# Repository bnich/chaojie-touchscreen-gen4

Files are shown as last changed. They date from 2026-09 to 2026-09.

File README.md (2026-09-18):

# Chaojie Gen 4 5" touchscreen — handlebar mount and rear cowl

A parametric, 3D-printable handlebar mount for the **Chaojie `CJ-V5-04`** 5" touchscreen display —
the panel sold with FarDriver controllers by E-Conic, EMF and others. It ships with no bracket.

<p align="center">
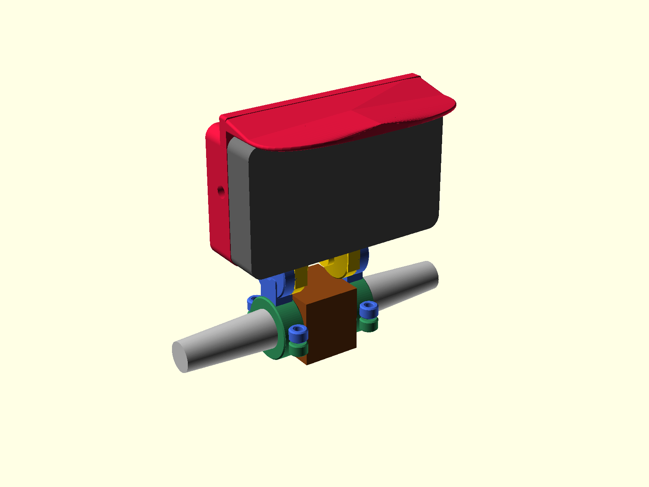
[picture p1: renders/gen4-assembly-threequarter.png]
Three-quarter render of the assembled mount: the display carried on a yoke with a toothed tilt joint at each side, two clamps on the handlebar either side of the centre bracket, and a red rear cowl with a curved sun visor projecting over the screen
  
</p>

A structural **yoke** bolts to the display's three M5 inserts and carries a 48-tooth face-spline tilt
joint at **each** side, on one shared axis parallel to the bar. Two **clamps** grip the handlebar on
**both** sides of the centre bracket. A **cowl** encloses the back of the display and carries a sun
visor over the glass.

| | |
|---|---|
| Printed parts | 4 distinct, **6 on the bike** (the clamp arm and cap print twice) |
| Tilt | 48 teeth, **7.5° per click**; tooth ring r = 12…20 mm, finest pitch 1.57 mm |
| Screen height above the bar | bottom edge **52 mm**, top edge **146 mm** |
| Grip on the bar | **~81 mm** total, split either side of the steering axis |
| Sun visor | **33 mm** past the glass; shades **27.7 %** of the screen at 45° off the screen normal |
| Material | ASA (PC or PETG-CF also suitable) |
| Filament | **262 cm³** for the six printed parts — about 320 g in ASA |

---

## Exploded view

<p align="center">
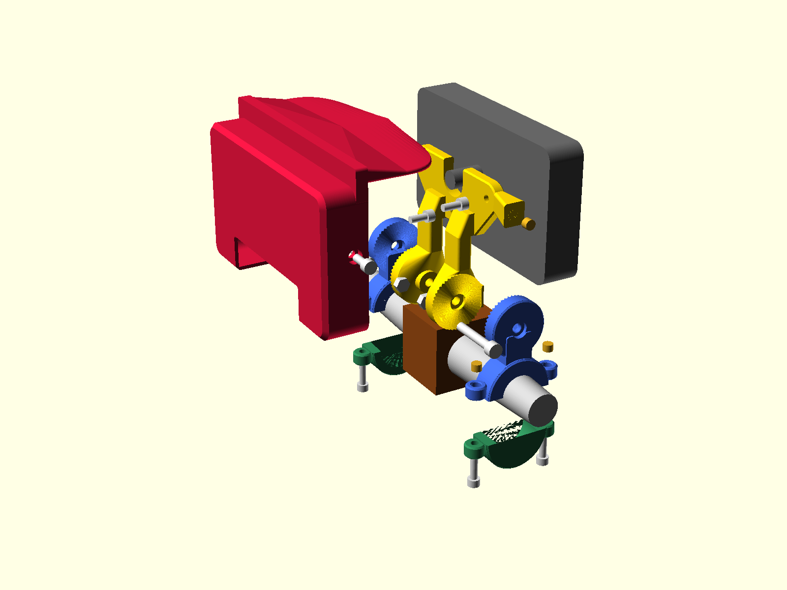
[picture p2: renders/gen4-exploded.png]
Exploded diagram: the red cowl with its two side screws, the gold yoke with three M5 bolts and two heat-set inserts, the grey display, and the two blue clamp arms with their green caps, clamp bolts, pivot bolts and nuts, on the silver handlebar either side of the brown centre bracket
  
</p>

| Colour | Item |
|---|---|
| Red | Cowl (printed) |
| Gold | Yoke (printed) |
| Blue | Clamp arm (printed, ×2) |
| Green | Clamp cap (printed, ×2) |
| Dark grey | Display — not printed |
| Silver / brown | Handlebar and its centre bracket — not printed |
| Brass | Heat-set inserts |

---

## Hardware

| Joint | Fastener | Count | Notes |
|---|---|---|---|
| Display → yoke | **M5 × 12** socket cap | 3 | ⚠️ **No washer, never longer.** The display's thread is 5 mm deep |
| Bar clamp, arm → cap | **M5 × 16** socket cap | 4 | Into inserts in the arm; heads counterbored into the cap's underside |
| Cowl → yoke | **M5 × 12** socket cap | 2 | Into inserts in the yoke's side ears; heads recess below the cowl's side face |
| Tilt pivot | **M6 × 35** + nyloc + plain washer | 2 | **One per side**, each through its own pivot only. 26.1 mm grip, 7.3 mm into the nut |
| Heat-set inserts | **M5, Ø7 × 5 long** | 6 | 4 across the two arms (2 per arm), 2 in the yoke; buy spares |
| Clamp bore liner | inner-tube rubber strip | 2 | Protects the bar and takes up ovality |

Medium-strength threadlocker on the three display bolts.

**Insert placement.** Two per clamp arm, pressed into the top face of each ear. Two in the yoke,
pressed into the outer face of each side ear. None in the cap, none in the cowl.

⛔ **No insert at the tilt pivot.** The M6 runs up the spline's own Ø12 central bore; an M6 insert is
Ø8 and would leave 2 mm of wall in the middle of the tooth ring. It is also the only joint here loaded
purely in tension, where a through-bolt and nut put the plastic in compression between two steel
faces. Use the through-bolt.

### Bolt lengths are derived

Each length is computed from the stack it crosses and asserted in the model. Change a part thickness
and the render stops and names the size it now needs.

```
pivot_grip = leg_w/2 + yoke_tip_h + spline_seat + arm_tip_h − pivot_head_sink
           = 9 + 6 + 7.6 + 6 − 2.5  =  26.1 mm   →  M6 × 35 with a 1.6 mm washer
```

---

## Does this fit my display?

It fits the **`CJ-V5-04`** — the 5", 800 × 480, DC 12–96 V panel with a `DJ7091A-2.8-11` 9-pin main
lead and a cable bundle emerging from the middle of its back.

It does **not** fit the 3" `CJ-V3-01` or the Gen 3 touchscreen — different housings, different hole
patterns.

<p align="center">
  Dimensioned rear-face drawing of the Chaojie CJ-V5-04: three M5 mounting holes at (39.50, 40.9), (120.50, 40.9) and (80.00, 63.28), the diameter 21.7 cable-boot collar at the centre, and the flat bearing band between Y 23.0 and Y 71.6
</p>

Three M5 holes, 81.0 mm apart, with a third 22.39 mm below the centre of that pair. Full dimensions
in [docs/display-geometry.md](docs/display-geometry.md).

---

## Fitting it to your bar

The clamp bore is a **cone**, not a cylinder, because the REVV1 FS bar tapers 1:10 through the clamp
zone. Measure the diameter at three points along the run — a single reading cannot tell a tapered bar
from a parallel one.

```openscad
bar_d0    = 32.0;   // Ø where the clamp's inboard face sits
bar_taper = 0.1;    // Ø lost per mm outward; 0 for a parallel bar
bar_run   = 20;     // usable straight length before the bar curves
arm_len   = 45;     // pivot above the bar centreline
```

Everything else is derived. See [docs/bike-fitment.md](docs/bike-fitment.md).

---

## Printing

ASA, 0.2 mm layers (0.16 mm for the cowl), 4 walls minimum, 40–50 % infill on the yoke and arms. The
cowl is designed around a 2.4 mm wall — six perimeters at 0.4 mm.

**Print order:** `insert_coupon` → `gauge` → `brow_test` → `yoke` → `arm` + `cap` (×2 each) → `cowl`.

Per-part orientation, measured overhang figures and settings: [docs/printing.md](docs/printing.md).

<p align="center">
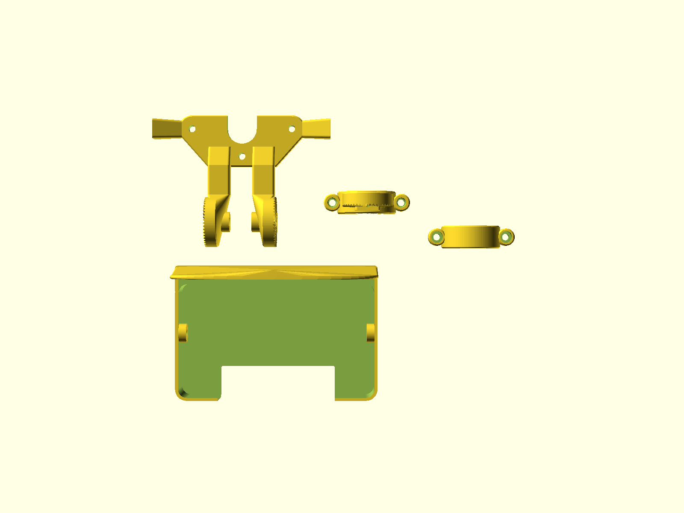
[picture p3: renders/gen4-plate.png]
The four printable parts -- yoke, arm, cap and cowl -- laid flat on one print plate in their print orientation
  
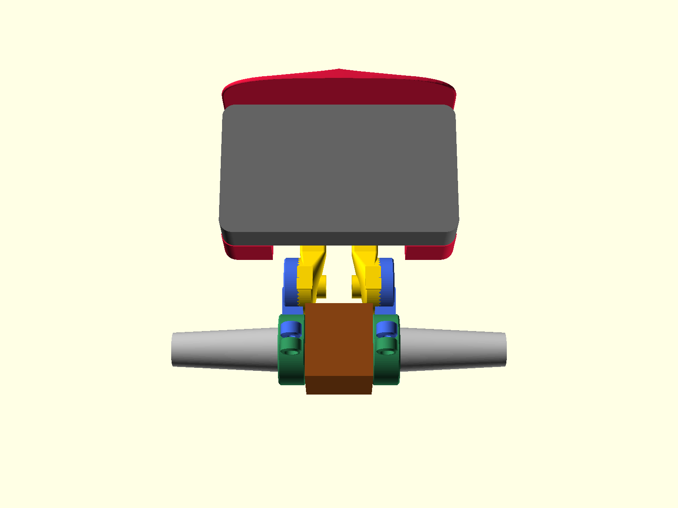
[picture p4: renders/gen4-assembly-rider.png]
The assembly seen from the saddle: the screen fills the frame with the sun visor across the top and both clamps visible flanking the centre bracket
  
</p>

---

## Assembly

1. Press the six heat-set inserts — two in each clamp arm, two in the yoke.
2. Bolt the yoke to the display — three M5 × 12, run down by hand first, then threadlocker.
3. Fit a clamp to each side of the centre bracket, butting its faces.
4. Mesh each spline at the angle you want and run the M6 through with its washer and nyloc.
5. Hook the cowl's top lip over the display's top edge, rotate it down, and drive one M5 × 12 into
   each side.

Full sequence, tilt adjustment and the 5 mm-thread warning: [docs/assembly.md](docs/assembly.md).

---

## Documentation

| | |
|---|---|
| **[docs/display-geometry.md](docs/display-geometry.md)** | Every measurement of the display's back, and the three things that catch people out |
| **[docs/design-notes.md](docs/design-notes.md)** | The design constraints and what each one protects |
| **[docs/bike-fitment.md](docs/bike-fitment.md)** | What the clamp needs from your handlebar, and how to adapt it to a different bar |
| **[docs/spline-verification.md](docs/spline-verification.md)** | How the tilt joint's teeth were proven to mesh, and why the obvious checks give wrong answers |
| **[docs/printing.md](docs/printing.md)** | Material, per-part orientation, measured overhang, settings, print order |
| **[docs/assembly.md](docs/assembly.md)** | Hardware, order of assembly, setting the tilt |

## Layout

```
src/      gen4-display-mount.scad   — the whole model; every part, one file
stl/      pre-built exports
renders/  drawings and preview images
docs/     the six documents above
tools/    build.sh          export every part and run every gate
          render-gen4.sh    every STL and every PNG
          check_stl.py      bounding box
          check_fit.py      clearance, on a second boolean engine
          check_throat.py   smallest load-bearing section, angle-swept
          check_fixing.py   does a screw cross one part and land in the other
          check_shade.py    what the sun visor actually shades
          check_necks.py    erode the part and see what falls off
          check_print.py    does any layer start in mid-air?
```

## Building from source

Needs [OpenSCAD](https://openscad.org/) (2021.01) and Python 3 with
`trimesh manifold3d numpy scipy networkx rtree`.

```bash
./tools/build.sh          # export every part, run every gate
./tools/render-gen4.sh    # the above, plus every PNG
openscad -o out.stl -D 'part="yoke"' src/gen4-display-mount.scad
```

Part names: `gauge`, `insert_coupon`, `spline_test`, `pivot_puck_test`, `yoke_leg_test`,
`yoke_plate_test`, `yoke`, `arm`, `cap`, `cowl`, `brow_test`, `plate`, `assembly`, `exploded`. An
unrecognised name fails loudly.

The build is gated on mesh integrity, fill against hand-computed expectations, minimum load-bearing
section over swept cutting planes, clearance between every part pair on a second boolean engine, that
the tilt joint pitches rather than rolls, that each screw crosses one part and lands in material in
the next, and what the sun visor measurably shades. Each gate has been run against geometry known to
be broken and confirmed to fail on it.

---

## Three things guarded by assertions

1. **The cable-boot slot opens upward.** A downward slot cuts off the lone M5.
2. **The pivot sits below the housing.** Anywhere higher and the toothed face covers that bolt's head.
3. **Bolt length minus part thickness lands in 3–4 mm.** The display's thread is 5 mm deep.

---

## Contributing

Issues and pull requests welcome — especially measurements from other units and photos of it fitted.
See [CONTRIBUTING.md](CONTRIBUTING.md).

## Licence

[CC BY-SA 4.0](LICENSE). Print it, modify it, sell prints of it — credit the source and share your
changes under the same terms.

The Chaojie factory manual is **not** redistributed here; it is Chaojie's document. The measurements
derived from it are facts and are published freely.

## Disclaimer

This mounts an electronic display to a moving vehicle. Nothing here has been tested to any standard.
**Proof-load it before you trust it, and re-check every fastener after the first ride.** You are
responsible for what you bolt to your own bike.

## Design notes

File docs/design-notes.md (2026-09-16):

# Design constraints

Read this before changing the model. Several things that look like arbitrary choices are forced by
the display, and "simplifying" them produces a part that renders fine and fails on the bike.

The model encodes each of these as an `assert()`, so if you change a parameter and break one, the
render stops and tells you which constraint you violated. **If an assertion fires, the number you
changed was wrong — not the assertion.**

---

## Two clamps, not one (2026-09-15)

The original design hung the whole display off **one** narrow yoke arm, necking down through the
cowl's opening to a **single** spline disc and **one** clamp on one side of the centre bracket — a
cantilever on a thin section, on a vehicle with no drivetrain damping. The owner rejected it:

> "That is a bad design. We should be attaching on both sides of the handlebars. There is a tiny
> sliver of plastic supporting the entire display."

Correct call — a two-sided mount was considered and discussed at design time, and it was wrongly
argued against then. Its advantages are exactly what a one-sided cantilever gives up:

- **Grip spread across ~81 mm** (an 18 mm clamp on each side of the 45 mm bracket) instead of 18 mm on
  one side of it.
- **The display centres itself.** With a spline on each side, mirror images of each other, there is no
  crank left to get wrong or drift out of sync with the bracket width — `pivot_x_r` (and its mirror
  `pivot_x_l`) is *derived* from the bracket's own measured 45 mm, not chosen and then checked against
  it after the fact.
- **A proper axle, not one disc taking the whole moment.** The tilt hinge is now a spline at *each* end
  of one shared axis, coaxial, each mating its own clamp — closer to a bicycle hub's two bearings than
  to a single boss cantilevered off a plate.
- **The load is shared and mostly in shear**, not a bending moment concentrated on one thin arm.

### One clamp part, mirrored, not two

`arm()`/`cap()` are unchanged in kind — still a two-piece bar clamp with a tapered bore and a male
spline — but there is now no `arm_crank`: each clamp roots its own spline at its own bare Y-midpoint
(`clamp_x0 + clamp_w/2`, no offset), and *the same printed part* is used on both sides. This works
because the clamp's own solid — round tube, symmetric ear bosses, a centred rib — is already
left-right symmetric about its own local X=0, and the male spline's tooth pattern (phase 0, an
arithmetic sequence of angles symmetric under negation) reproduces itself exactly under a mirror about
any plane containing its own axis. `clamp_seat(side)` (the renamed, generalised `arm_seat()`) seats the
right clamp with the same translate/rotate this file has always used, and seats the left one as
`mirror([1,0,0])` of that exact result — not a second, independently-solved rotation. The one subtlety
worth recording: mirroring about the plane **perpendicular to** the shared hinge axis (X=0, and the
hinge runs along X) **commutes** with the pitch rotation `theta`, because a reflection whose own axis
*is* the rotation axis negates both the axis and the angle, and the two negations cancel — so both
clamps use the *same* `theta`, not opposite-signed ones. Confirmed against the actual exported geometry
by the same pitch-acceptance test described below, not trusted on the algebra alone.

⚠️ **Left side of the bar is unmeasured.** Only the right side was put under calipers
(`docs/bike-fitment.md`). `bar_d0`/`bar_taper`/`bar_run` are **temporarily assumed** to mirror on the
left — flagged at their own definition in `src/gen4-display-mount.scad`. If the left side turns out to
differ, the two clamps stop being one shared part.

### Minimum cross-section in the load path

⭐ **Corrected 2026-09-15, after a real defect.** This table used to claim no station on the path was a
thin cantilevered sliver, including a rising-rib figure (`arm_w × ~8mm = 160mm²`) that was never
actually measured — a hand guess from the two end profiles, not a scan of the part in between. The
owner found the truth by eye: *"Ensure that there is enough material holding the clamp to the
handlebars to the toothed piece. It looks very thin."* They were right. A station-by-station section
scan (`tools/build.sh`, added the same day — intersect the part with a 1mm slab at each station,
volume ÷ thickness) confirmed it: the clamp's own rising rib had a "vertical riser" stage built from
two `taper_wp()` waypoints at the *same* Y, which cannot gain any real Y-thickness — a `hull()` between
two same-Y markers stays confined to that marker's own 0.2mm thickness for its entire run (the
mechanism, not just the number: `src/gen4-display-mount.scad`'s own block comment above `arm()`'s Stage
1). Measured minimum: **4 mm²** — a 20mm-wide, 0.2mm-thick knife edge — not the claimed 160. Every
other check stayed green throughout: watertight, 0 boundary, 0 non-manifold, 1 component, a plausible
total volume, clearance clean, a normal-looking render. None of them measure a cross-section; volume
catches a hollow part, nothing was watching minimum section. Fixed by widening that riser to a real
Y-span (`clamp_riser_y0`..`clamp_riser_y1`, 14mm, inboard of the clamp tube's own edges) instead of a
single Y. `tools/build.sh` now scans every station along both this path and the yoke leg's own, and
fails the build if either drops below a floor — the permanent check the project didn't have before.

### ⚠️ A section scan is only as honest as the plane it cuts on

The scan above cuts perpendicular to one axis. On the yoke, that axis was the one direction the weak
spot looked strong in, and the scan passed a leg that was hanging off the bearing plate by almost
nothing. Owner, looking at the side view: *"there is only a thin bit of plastic connecting where the
back of the part mounts to the display to the rest of the yoke, this should be thicker."* Right again,
and again after a check had passed it.

The cause is a genuine constraint collision. Material at low Z has to stay inside the display's flat
band (outside it the rear shell chamfers away), which confines the leg's climb from the plate to the
riser — **13 mm of Z across 2.32 mm of Y**, a slope of 5.6:1. That is not a taper, it is a shear web
18 mm wide and about 2 mm thick. Cut across Y it measures 194.6 mm²; cut at 72–78°, the way the load
actually peels the leg off the plate, it measures **36.4 mm²**.

**The fix is a gusset**, not a wider Stage A — the 2.32 mm is forced and that constraint is real.
Instead the load now also runs through the one place with no clearance constraint at all: directly
above the bearing plate. A wedge buried `yoke_gusset_bite` (3 mm) into the plate's top face runs north
to just clear of the boot's relief pocket and ramps up to meet the riser. The plate is solid 18-of-18
mm under the leg's whole X band there (measured on `yoke-plate-test.stl`, not assumed), so the
gusset's underside is fully carried: **no overhang, no support, and the yoke's down-facing area is
unchanged at 2644 mm²**. Throat **36.4 → 182.2 mm², a 5× improvement**, for 4.3 cm³ of extra plastic.

`tools/check_throat.py` is the permanent check. It does not pick a plane: it sweeps the cutting angle
and reports the smallest section that *verifiably separates* the load's origin from its destination —
cut the solid, and the piece holding the destination must not hold the origin. Without that
separation test the search just finds the part's own edges, where a plane clips a corner and the area
tends to zero. It gates the yoke at 150 mm² and the arm at 200 mm², and it was proven to fire against
the pre-gusset geometry (36.7 mm², 113 mm² under the floor).

Walking the path today — every figure measured, none estimated from end profiles:

| Station | Cross-section (measured) |
|---|---|
| Bearing plate (bolted to the display) | `yoke_t` (8 mm) full-thickness slab, widened at its base to root both legs |
| **Plate → pivot, worst plane at any angle** | **182.2 mm²** per leg (was 36.4 mm² before the gusset) |
| Each leg's own run, cut across Y | ~194 mm² per leg |
| The spline (each pivot) | Ø40 Hirth coupling, all 48 teeth engaging at once across a ~1144 mm² annulus — a distributed contact, not a point |
| Each clamp's own rising rib | **284 mm² minimum** (widened 2026-09-15 from a 4 mm² knife edge — see above) |
| Clamp → male spline, worst plane at any angle | **236.9 mm²** — measured the same swept way, so the arm is known clear of this failure mode rather than assumed clear |
| Each clamp body | Ø48 tube over a ≥Ø28 bore — a ring, not a sliver |

**The minimum on the whole path is now the leg's own run, ~182–194 mm² per leg, and there are two of
them in parallel.** That is the right place for the limit to sit: it is uniform section, not a
junction. It is set by `leg_w` = 18 mm, reduced from the old single arm's 26 mm as a deliberate trade
for clearance from the lone M5's socket sweep (the legs are no longer centred under it — see
`pivot_x_r`'s own assertion in the model), not as a structural economy. There is headroom to widen it
again if a print or a ride ever calls for it.

---

## The two forced constraints

### 1. The boot slot opens upward

Covered in [display-geometry.md §4.3](display-geometry.md). Short version: the loom exits the middle
of the back, its connectors are too big to thread through any closed hole, and a downward slot would
cut off the lone M5. Up the centreline is the only direction that works.

This is why the bearing plate is a wide, gusseted shape — three bolt pads plus two more hull anchors
(one per leg root, ⭐ 2026-09-15) — rather than a plain rectangle: every anchor has to stay clipped to
the flat band and clear of the boot's own upward slot.

### 2. The pivot sits well below the housing — DM-6, re-derived for a bar-parallel axis

**The tilt joint's axis has to be parallel to the handlebar**, not the display's own normal. A hinge
that swings the display's pitch (up/down, the whole point of a tilt mount) needs its axis running
across the bike, the same line the bar lies on — turning about the display's own normal instead just
rolls the screen in its own plane, which is a defect this design carried and fixed once (2026-09-14),
documented here so the reasoning survives, not the mistake.

That axis choice changes what "the pivot sits below the housing" has to defend against. With the axis
along the bar (model X), the toothed face's own reach along its axis is only a few millimetres — it
sits deep inside the display's own width, with no sideways offset to hide behind the way a normal-axis
boss could hide behind standoff depth. Clearance for both the display and the lone M5 has to come from
where the disc sits in the OTHER two axes (Y and Z), not from how far it stands off in Z.

**The display.** The disc is a Ø40 circle in the Y-Z plane. Placed entirely below the display's own
bottom edge in Y (rather than split across a Y/Z diagonal — simpler to build and reason about, and it
costs nothing since there is open air below the display anyway), it needs no Z clearance to avoid the
housing at all: its bottom edge is at model Y −70, 23 mm below the display's own bottom edge, so even
at the disc's nearest point (Y −50) there is a full 3 mm of air past the housing.

**The lone M5.** Automatically satisfied by the same margin — the bolt sits at model Y −16.3, deep
inside the display's own footprint, far closer to the display than to a pivot 70 mm below it. The
connecting arm's own root/riser staging (unchanged by this rework) still keeps material flush at the
bearing-plate thickness until it is past the bolt's own Y, exactly as before, so nothing between the
plate and the disc can shadow the bolt either.

**The cost, twice over.** The display's centre of mass now sits **70 mm** above the pivot (was 53 mm)
— on a ~0.4 kg display, ~0.34 N·m static, still comfortably inside what this spline is sized for. And
because both clearances (display, and the clamp-vs-spline check in `docs/bike-fitment.md`) now stack
on the SAME axis instead of two independent ones, the display sits **52 mm** above the bar's top
surface at the reference (theta=0) pose instead of the originally-chosen 35 mm — see
`docs/bike-fitment.md` for the full number and why a more compact, diagonal-clearance placement was
not pursued.

---

## Why a toothed face spline, not friction

A friction pivot — a bolt clamping two smooth faces — is the obvious cheap answer and it is the wrong
one here. Plastic-on-plastic under vibration relaxes; on a hub-motor vehicle with no drivetrain
damping it will need re-nipping, and eventually the faces polish and it stops holding at all. A
screen that droops at 40 mph is a permanent small annoyance.

A face spline carries the moment on **teeth** instead of friction, so an angle set today is still set
in a year. You trade infinite adjustment for 7.5° steps.

**Why a printed spline is trustworthy:** a face spline engages *every tooth at once*. With 48 teeth
the per-tooth load is tiny, so FDM's weakness across layer lines stops governing — which is what lets
the yoke print flat on its bearing face, the orientation its plate and bolt pads want anyway.

The model carries a **`teeth = false`** switch. Once you have settled on an angle from riding, the
same file prints the joint solid, with nothing left to loosen.

---

## Why two parts instead of one

The back of this display faces forward on a moped — it is a surface people see, not a bracket hidden
behind a screen. So there is a cosmetic cowl over the structural yoke.

Splitting them lets each be optimised separately:

- the **yoke** is oriented and ribbed for strength, and printed bearing-face-down;
- the **cowl** is thin-walled and printed **face-down on a textured sheet**, so the surface people see
  is one uniform moulded-looking texture instead of stacked layer lines.

It also means the cowl comes off for service **without ever disturbing those 5 mm threads**, which is
the fastener you least want to cycle.

---

## The sun visor

The cowl carries a visor over the glass. It is not decoration. Chaojie does not publish this panel's
brightness, and it is a 5" glossy screen on an open vehicle — daylight readability is its real
weakness. The visor costs nothing to print as part of a cowl you are making anyway, and it keeps rain
and low winter sun off the glass too.

### What it measures

`tools/check_shade.py` fires rays at the glass from a given sun angle and reports what fraction of
the screen the cowl actually blocks. The angle is measured **from the screen's own normal**, not from
the horizon — so "45°" means the sun is 45° off the direction the screen is pointing, whatever the
tilt joint is set to. That is the quantity that decides shading; world elevation is not.

| Sun, off the screen normal | Screen shaded | Shadow reaches, from the top edge |
|---|---|---|
| 45° | **27.7 %** | 28.2 mm |
| 60° | 49.3 % | 49.3 mm |
| 75° | 94.0 % | 94.0 mm |

Projection past the glass is **33 mm**. `tools/build.sh` holds a 20 % floor at 45°.

### ⚠️ Width is the lever, not projection

The obvious way to shade more is a longer nose. It does almost nothing here, and this was measured
rather than argued. On the earlier straight-taper visor, stretching projection from 33 mm to 45 mm
moved 45° shade 14.8 % → 17.2 %, and 60 mm reached only 20.4 % — while the shadow's depth down the
screen did not move at all, staying at 14.1 mm in every case. A row of screen is shaded only where
the visor is actually *over* it, so a visor that has tapered to a 2 mm spike by mid-projection leaves
the screen's outer columns in full sun however far that spike reaches.

So the plan curve is a **superellipse** (`brow_plan_n = 3`): full width at the glass plane, holding
most of it for most of the run, then turning back to a blunt rounded nose over the last few
millimetres. Same projection, same rounded silhouette, 27.7 % instead of 14.8 %. Raising the exponent
squares the curve off — more shade, blockier nose; lowering it toward 2 gives a sleek ellipse and
less shade. Move it and re-run the shade test.

### ⚠️ The bearing plate is a truss — its reach depends on Y

The plate is not a rectangle. Its outer edge runs diagonally from the bolt-hole wings down toward the
legs, so how far out in X it reaches depends strongly on where in Y you look:

| Y | plate reaches |
|---|---|
| +6 | **x = 51.5** (widest) |
| −4 | x = 46.0 |
| −12 | x = 39.0 |
| −24 | x = 28.2 |

Anything rooted into the plate has to be placed against that, not against its bounding box. The cowl's
side ears were first placed at y = −4 starting at x = 51 — five millimetres outboard of the plate
altogether, meeting it at a corner, sharing **2.3 mm³** of volume with it out of 6670. They are now at
**y = +6**, the widest line, rooted at x = 40 where the plate is solid from y = −10 to +16.

⛔ **A section scan cannot catch that class of defect at any angle**, including the hemisphere sweep
in `tools/check_throat.py`, which reported 112 mm² on the broken ear. The plane that comes closest to
separating an ear also slices a large area of plate carrying none of the ear's load. To ask whether a
feature is *attached*, measure the **shared volume** of the two solids — `tools/build.sh`'s cowl-ear
bond gate — not a cross-section.

### The underside is flat on purpose

Every station's profile sits on one shared plane, `brow_y0` (3 mm above the display's top edge).
Drooping the nose would shade more, and it is tempting — but the visor extends *toward the rider*,
and anything that shades the sun at a given angle also blocks the rider's eye at that angle. A drooped
nose eats the top of the screen from an upright riding position. Shade above ~45° is what the tilt
joint is for: point the screen at your eyes and the sun goes off-normal without the visor moving.

⬜ **Not bench-verified.** Print `brow_test` and hold it against the screen on the bike, seated
normally, before committing the cowl. The numbers above are ray-cast measurements of the model, not
of a printed part in sunlight.

---

## Making it look like a product rather than a print

Applied without exception:

| | |
|---|---|
| **R3 / R2 / R1** | **No edge is left sharp.** R3 on the cowl's outer perimeter, R2 on every other visible edge, R1 internal fillets at every wall-to-rib junction. The internal ones are not cosmetic — a sharp internal corner is where a printed part cracks |
| **R9 corners** | the cowl's corner radius **is the display's own**, so the two read as one object rather than two stacked ones |
| **0.5 mm reveal** | a **deliberate, even shadow gap** where the cowl meets the display, all the way round — not an attempt at zero. A consistent reveal reads as designed; a gap wandering from 0 to 0.6 reads as a bad fit. ⭐ This single detail does more than any other to separate "professional" from "printed" |
| **Uniform wall** | 2.4 mm throughout the cowl (6 perimeters at 0.4). Constant wall keeps the surface even and avoids dimpling where a thick section meets a thin one |
| **No visible fixings** | from the front there is nothing but shell. Both cowl screws go **upward through the bottom rim**, where only the road sees them |
| **Chamfered lead-ins** | 0.5 × 45° on every bolt hole and mating edge — assembly feels positive, and first-layer elephant-foot cannot foul the fit |

---

## Things deliberately not done

**No quick-release.** **The loom is moulded into the display**, with no connector at the screen end,
so a lift-off mount would hand you a screen still tethered to the bike. It only becomes worth building
if you put a connector in the loom yourself.

**No microphone port.** The cowl covers the mic hole at (80.2, 76.0) and it stays covered, keeping the
visible face unbroken. The cost is that CarPlay call audio into the display's own mic is gone. If you
want it, add a short slot or a group of Ø1.5 holes over that position — but a phone or helmet mic is
the better answer than cutting this shell.

---

## Origin

Designed for a Ride1Up REVV1 FS converted to a 5 kW hub motor, where this display replaces the stock
dash. Nothing in the mount is specific to that bike except the handlebar clamp diameter, which is a
parameter.

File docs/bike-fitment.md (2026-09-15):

# Fitting it to the bike

What the clamps need from your handlebar, and where the screen ends up. Measured on a
**Ride1Up REVV1 FS**; the numbers are parameters, so adapting to another bar is a matter of
remeasuring rather than remodelling.

⭐ **Two-clamp mount (2026-09-15).** The mount clamps the bar on **both** sides of the centre
bracket — one clamp butting each of its two faces — instead of a single clamp on one side. The owner
rejected the original one-sided design as structurally inadequate ("a tiny sliver of plastic
supporting the entire display"); see `docs/design-notes.md` for the full reasoning. **Both clamps are
the same printed part** (`arm`/`cap`), so print two of each.

---

## ⚠️ The bar is tapered

This is the fact the clamps turn on, and it is easy to miss because the *grip* ends of these bars are
a constant 22.2 mm.

A **45 mm wide bracket** clamps the bar to the bike, on the centreline, with a clamp butting each of
its two faces. Measuring outward from the bracket's **right-hand** face:

| Distance from the bracket face | Bar Ø |
|---|---|
| 0 mm | **32.0** |
| 10 mm | **31.0** |
| 20 mm | **30.0** |
| beyond 20 mm | the bar curves upward — unusable |

Perfectly linear: **Ø = 32.0 − 0.1·x**. A **1:10 taper on diameter**, half-angle ≈ **2.86°**. 32 mm is
1.25″, so this is a standard oversize moto bar tapering toward 22.2 mm at the grips.

⬜ **TEMPORARY VALUE — the left side has not been measured.** Only the right side (above) was put
under calipers. The left side's `bar_d0`/`bar_taper`/`bar_run` are **assumed to mirror the right**
exactly, flagged in `src/gen4-display-mount.scad` at their definition. **Confirm the left side on the
bike before printing the left clamp for real** — measure the diameter at 0/10/20 mm from the
bracket's left face, at more than one clock angle. If it differs even slightly, the two clamps stop
being one shared part: split `bar_d0`/`bar_taper`/`bar_run` into `_r`/`_l` pairs and give the left
clamp its own `bore_at()`.

### What it forces

**The bore is a cone, not a cylinder.** A cylindrical bore on a tapered bar contacts on a *line* at
its large end only. Across an 18 mm clamp the diameter changes 1.8 mm — roughly nine times print
tolerance, far too much to take up by squeezing. In the model:

```openscad
bar_d0    = 32.0;   // Ø at the bracket face
bar_taper = 0.1;    // Ø lost per mm outward
bar_run   = 20;     // usable straight length
```

**Each clamp is 18 mm wide**, because 20 mm is the entire usable run on each side.

**Butt each clamp against its own face of the bracket.** The taper means a clamp can only creep
*outboard*, into a smaller diameter; the bracket blocks the inboard direction mechanically. So if one
ever does move it goes **visibly loose** rather than failing quietly. ⚠️ That is a reason to inspect
it, not a reason to trust it.

---

## ⚠️ Reroute the cables first

On this bike at least two cables cross the bar through the clamp zones. **Move them behind or under
the bar before either clamp goes on.** A cable trapped under a clamped bore chafes through
eventually, and the damage is invisible until it is not.

---

## Where the screen ends up

Nothing obstructs above the bar on this bike, so height is an ergonomic choice — but there is a hard
floor. Each clamp body is about Ø48 over a Ø34.3 bore, so its top sits **24 mm above the bar's
centreline**, and the tilt spline is Ø40. For the spline to clear its own clamp the pivot must be at
least ~45 mm above the centreline. Lower than that and the leg has to reach backward instead of up,
which is a different part. This is a **per-clamp** clearance fact — it doesn't depend on how far
apart the two clamps sit — so it is unchanged by the two-clamp rework.

The lowest workable position is the default:

| | mm |
|---|---|
| `arm_len` — each pivot's centre above its own clamp's bar centreline | **45** |
| Display **bottom** edge above the bar's top surface | **52** |
| Display **top** edge above the bar's top surface | 146 |

⭐ **No crank any more.** The old single-clamp design needed `arm_crank` (32.5 mm) to drag its one
off-centre clamp's pivot back to the bike's centreline. With a clamp — and a spline — on **each**
side, the display centres itself between the two pivots by construction: the yoke's two female
splines sit at `±pivot_x_r`, mirror images of each other, and there is no crank parameter left to
drift out of sync with the bracket width. `pivot_x_r` is **derived** from the bracket's own 45 mm
width, not chosen — see `src/gen4-display-mount.scad`'s own comment above `pivot_x_r` for the closed
form.

The 52/146 mm figures are **unchanged from the single-clamp design** — the two-clamp rework only
moved things sideways (X: where the clamps and the two pivots sit relative to the bracket), never up,
down, forward or back (Y/Z: `arm_len`, `bar_d0`, `pivot_y` are all the same numbers as before), so the
screen's height above the bar carries over exactly.

⚠️ **Height above the bar is no longer independent of tilt.** A joint that actually pitches means
tilting the display swings its centroid — and so the whole assembly's reach — up/down and back/forth
around the pivot axis. The 52/146 mm figures above are for the **reference pose**
(`arm_seat_theta = 0` in `src/gen4-display-mount.scad`, the pose every render and clearance check in
this repo uses); a different one of the 48 valid 7.5° click positions puts the screen at a measurably
different height. This is expected — it is the whole point of a working tilt joint — not a modelling
error.

---

## Grip spread

The old single clamp gripped the bar over 18 mm, on one side of the bracket only. The two-clamp mount
grips over **~81 mm total** — an 18 mm clamp on each side of the 45 mm bracket (`45 + 2×18`) — spread
across both sides of the steering axis instead of hanging everything off a cantilever on one side of
it. This is the structural point of the rework, not a side effect of it.

---

## Adapting to a different bar

Remeasure and change four numbers (**on both sides** — see the ⬜ flag above):

```openscad
bar_d0    = 32.0;   // Ø where each clamp's inboard face will sit
bar_taper = 0.1;    // 0 for a parallel bar
bar_run   = 20;     // usable straight length
arm_len   = 45;     // pivot above the bar centreline — see the floor above
```

**Measure the diameter at three points along the run, on BOTH sides, not one reading on one side.** A
single reading cannot tell a tapered bar from a parallel one, and the difference decides whether the
bore is a cone or a cylinder. Take each reading at more than one clock angle too — a used bar goes
oval where clamps have sat. If the two sides differ, split `bar_d0`/`bar_taper`/`bar_run` into
`_r`/`_l` pairs — the two clamps are no longer one shared part.

If your bar is parallel, set `bar_taper = 0` and the bore becomes a cylinder; nothing else changes.

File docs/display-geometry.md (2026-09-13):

# Chaojie `CJ-V5-04` — measured geometry

Everything a mount needs to know about the back of this display. If you are designing your own
bracket rather than printing ours, this page is the useful part of the repository.

> **Source.** These figures come from the factory manual's **§III Installation dimensions** drawing,
> plus direct measurement of one unit. The manual itself is Chaojie's copyrighted document and is
> **not redistributed here** — ask your reseller for it. Dimensions are facts; the document is not
> ours to share.

---

## 1. How reliable these figures are

**Confirmed on a physical unit:** the hole pattern (a printed gauge bolted to a display), the thread
size and depth, the up/down orientation, that the Ø13 stub is the cable bundle, and the flat bearing
band.

**Taken from the manual's §III dimensioned drawing:** everything else — the Y of the upper hole row,
the boot and collar diameters, the microphone position, the case-screw positions.

The drawing is true to scale: its own printed 159.99 and 93.98 give 5.6754 and 5.6608 px/mm at
600 dpi, agreeing to 0.26 %, and figures measured off it match every printed callout to within a line
width. Treat the drawing-derived figures as good to a few tenths, and the confirmed ones as exact.

---

## 2. Datum

**Stand the display upright, screen facing away from you, so you are looking at its back.**
**X** runs from the left edge as you see it, **Y** runs *down* from the top edge.

⭐ **Every feature on the rear face is mirror-symmetric about X = 80**, to within 0.3 mm — both upper
holes, the lone hole, the cable boot, the microphone and all five case screws. **So left/right cannot
be got wrong.** Only the up/down orientation matters, and the lone hole is **below** the pair.

---

## 3. The numbers

| | mm | Notes |
|---|---|---|
| Housing | **159.99 × 93.98 × 26** | the 26 is rear face → glass and **excludes the cable boot** |
| Corner radius | **9** | reuse it on your cowl and the two read as one object |
| Mounting holes | **M5 × 3, 5 mm deep** | ⚠️ see §4 |
| — upper left | **(39.50, 40.9)** | |
| — upper right | **(120.50, 40.9)** | the pair is **81.0 apart and dead level** |
| — lone hole | **(80.00, 63.28)** | **on the centreline**, 22.39 below the pair |
| — triangle sides | slant sides **46.46** each | isosceles |
| Flat bearing band | **Y 23.0 … 71.6** | 48.6 mm strip; outside it the shell chamfers away. See §4.2 |
| Cable boot | **Ø13.0 × 22.3 proud**, in a **Ø21.7** collar, at **(80.0, 40.9)** | total depth over it **47.8** |
| Microphone | **(80.2, 76.0)** | labelled 送话器孔 on the drawing |
| Case screws | (10.8, 11.0) · (80.1, 9.9) · (149.5, 11.0) · (33.1, 84.2) · (127.3, 84.2) | ~Ø8.5 pockets |

---

## 4. ⚠️ The three things that will catch you out

### 4.1 The threads are 5 mm deep — one bolt diameter

That is **short**. Bolt length minus your part's thickness must land in **3–4 mm**: enough engagement
to hold, with at least 1 mm of air so the bolt can never bottom.

**A bolt that bottoms feels tight and is holding nothing.** Run each one down by hand and confirm it
pulls the bracket tight rather than stopping against the bottom of the hole. Use a medium
threadlocker and modest torque spread across three points — this is not a joint to crank on.

This repository's parts are **8 mm** thick and use **M5 × 12** (4 mm engaged). M5 × 8 with 5 mm parts
works equally well if that is what you stock. **No washer under the head** — it eats engagement you
do not have.

### 4.2 You can only bear on the flat band, Y 23.0 … 71.6

Outside that 48.6 mm strip the shell chamfers away. A bracket that touches beyond it is rocking on
two lines instead of sitting on a face, and it will work the bolts loose. All three holes sit inside
the band — the lone one with 8.3 mm to spare.

⚠️ **If you derive this yourself from the manual, you will get 20.0 … 74.6 and it is ~3 mm optimistic
at each end.** The side elevation shows where the surface *begins* to chamfer; the genuinely flat area
stops inboard of that line. Use the measured figures above.

⬜ Measured off a fitted gauge by eye, good to ~±1 mm.

### 4.3 The cable boot is **inside** the bolt triangle

The whole loom — 9-pin main, speaker, camera, USB — leaves the display through a **Ø13 boot standing
22.3 mm proud** at (80.0, 40.9). That is 22.4 mm above the lone hole and 40.7 from each upper one.

**So a flat plate cannot bolt to this display.** You need a central opening of at least **Ø24** (size
it on the collar, not the boot).

And the opening **must run out to an edge**. The connectors on that loom are all larger than any hole
the bolt pattern leaves room for, so you cannot thread them through. It cannot run *downward* — the
lone M5 is on the centreline directly below the boot and a downward slot cuts it off. **Up the
centreline severs nothing**, because the upper holes are ±40.5 out.

⭐ The good news: the slot is only needed to get the bracket **on and off**. The boot stands 22.3 mm
proud of an 8 mm plate, so the wires fan out *behind* the bracket and route freely. Nothing passes
through the slot in service.

---

## 5. Electrical, for context

Not needed to mount the thing, but it is what people ask next.

| | |
|---|---|
| Operating voltage | **DC 12–96 V** |
| Screen | 5", 800 × 480, touch |
| Protection | IP65, −20 … +70 °C |
| Main connector | `DJ7091A-2.8-11`, 9-pin |
| Controller link | one-line on **pin 9** (0–15 V) |
| Pins 7 / 8 | CAN, described by the manual as **battery**-facing (BMS), not controller |
| Audio | 10 W / 4 Ω, one speaker, on a 2-pin `DJ7021-2.8-21` |
| Other leads | round 4-pin camera, USB-A for firmware |

⚠️ **Pin 9 idles at ground (~9 mV) and does not bias the line** — whatever drives it must supply the
high level itself. Its input is **≈6.4 kΩ to ground**, not high impedance, so the driver has to source
real current.

⚠️ **The flying leads are stranded.** Pushed into a solderless breadboard they splay and make no
contact while looking perfectly seated. Tin, ferrule or solder to solid-core first.

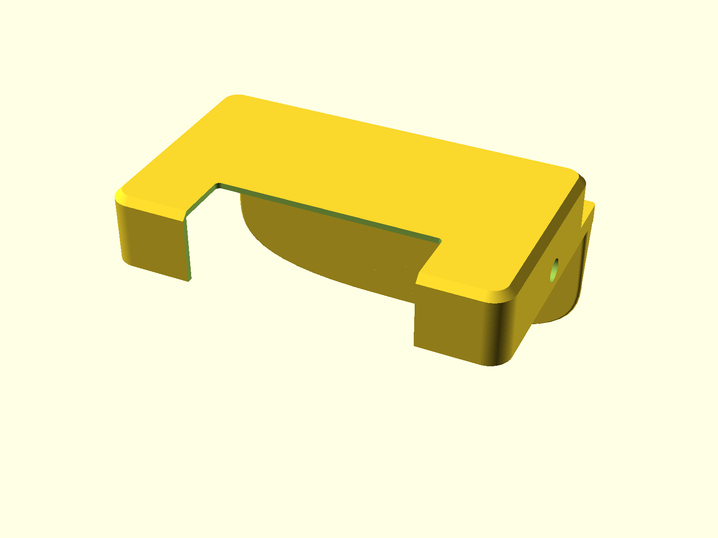
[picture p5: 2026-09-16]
renders/gen4-cowl.png

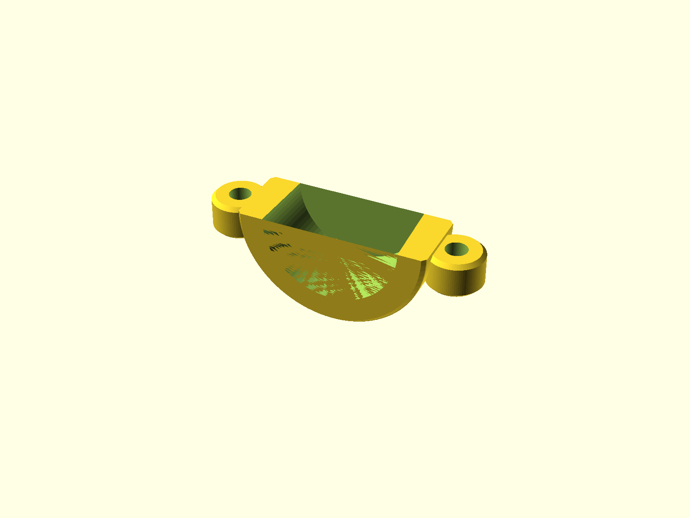
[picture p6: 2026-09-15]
renders/gen4-cap.png

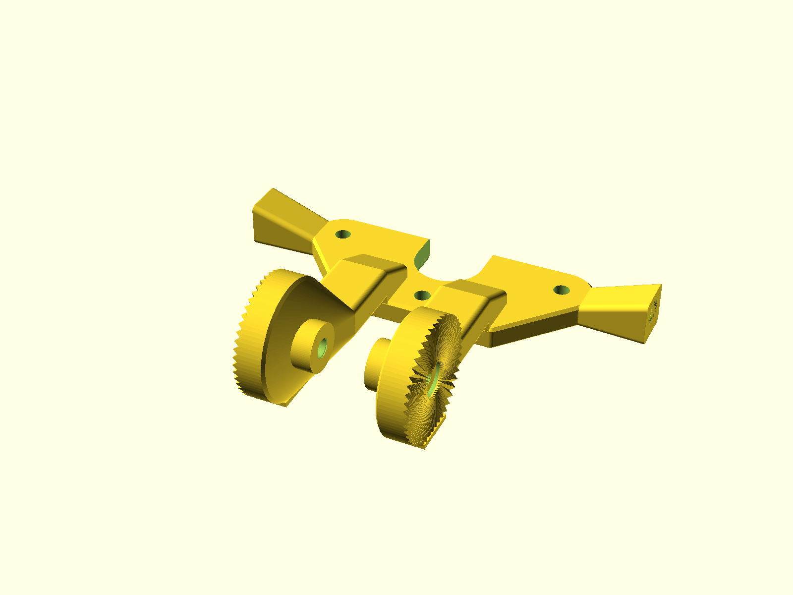
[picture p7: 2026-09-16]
renders/gen4-yoke.png

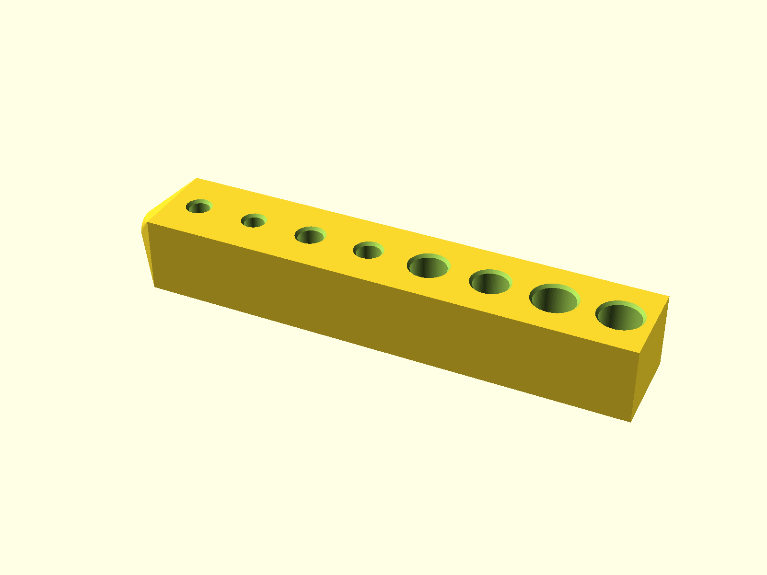
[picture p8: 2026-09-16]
renders/gen4-insert-coupon.png

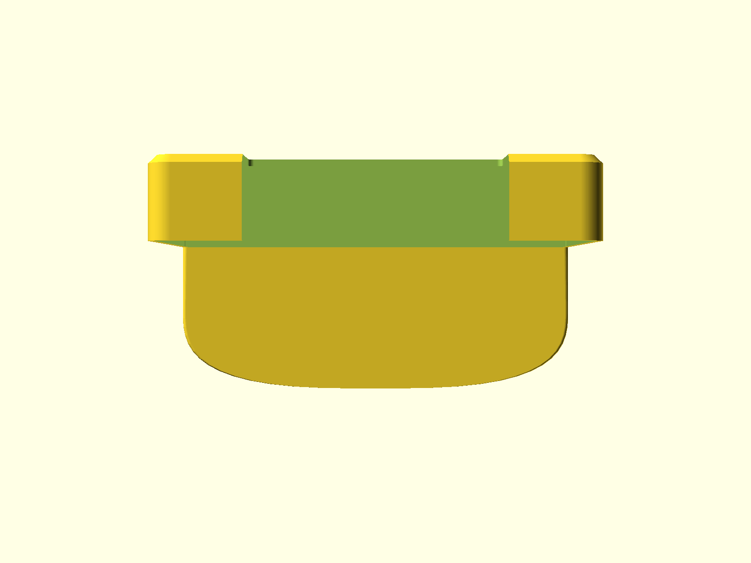
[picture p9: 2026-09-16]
renders/gen4-visor-plan.png

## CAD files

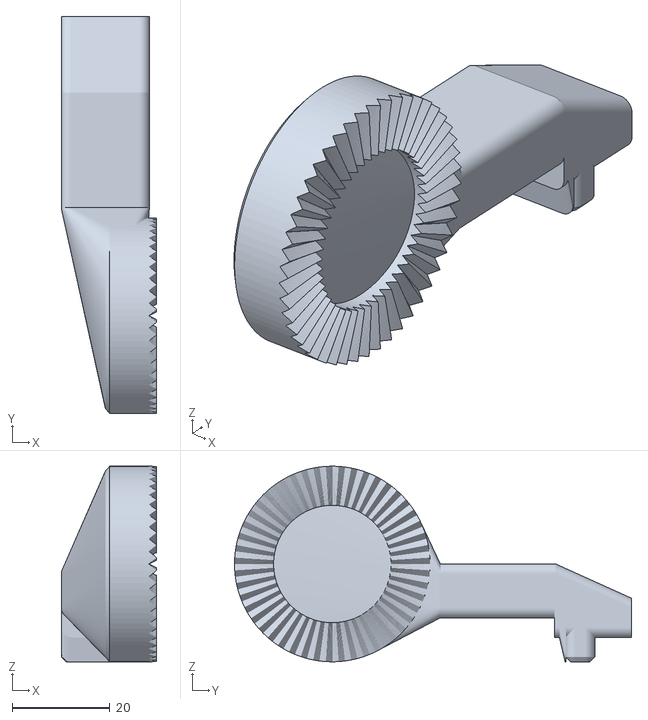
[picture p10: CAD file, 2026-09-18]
stl/gen4-yoke-leg-test.stl
19.5 x 81.2 x 40.0

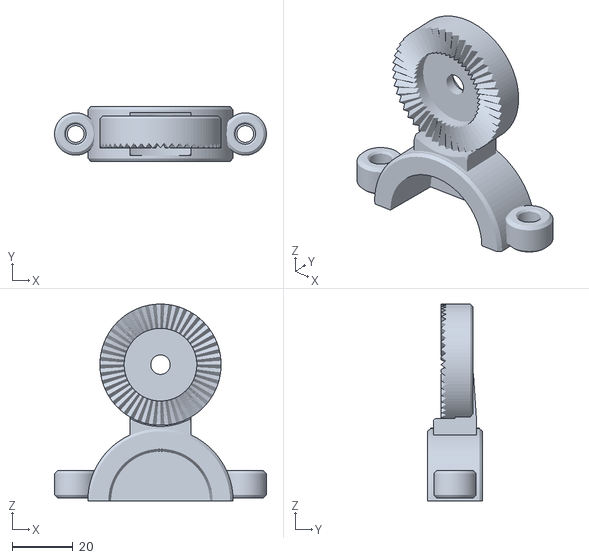
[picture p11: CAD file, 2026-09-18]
stl/gen4-arm.stl
70.0 x 18.2 x 65.0

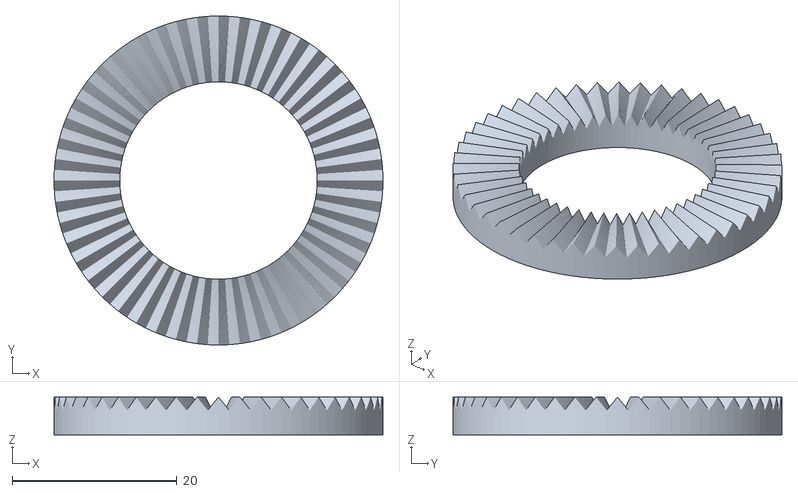
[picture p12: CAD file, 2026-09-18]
stl/gen4-spline-test.stl
40.0 x 40.0 x 4.60

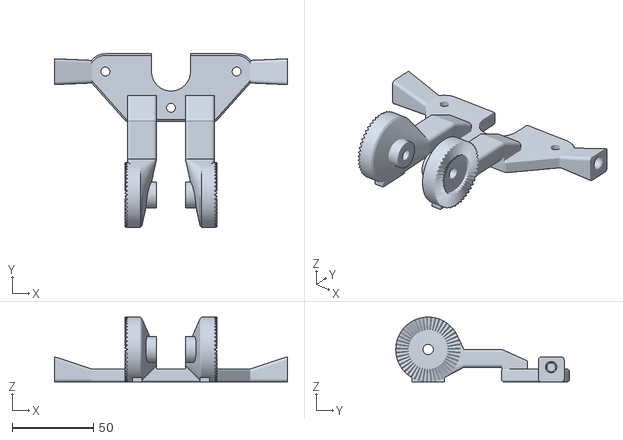
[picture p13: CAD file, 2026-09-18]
stl/gen4-yoke.stl
143.8 x 107.1 x 40.0

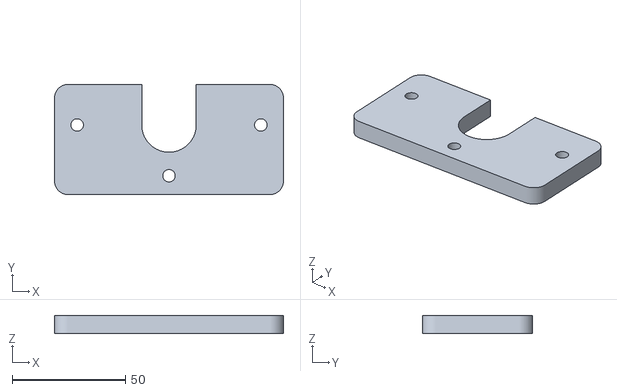
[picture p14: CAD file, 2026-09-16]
stl/gen4-gauge.stl
101.0 x 48.6 x 8.00

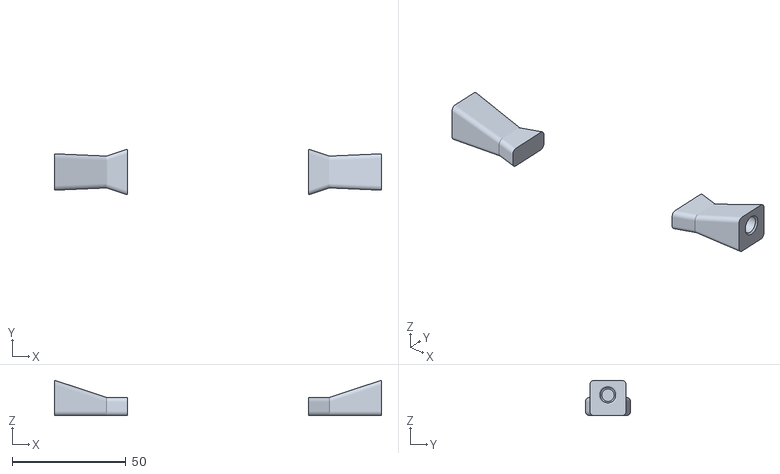
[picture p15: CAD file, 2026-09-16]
stl/gen4-yoke-ear-test.stl
143.8 x 20.0 x 15.5

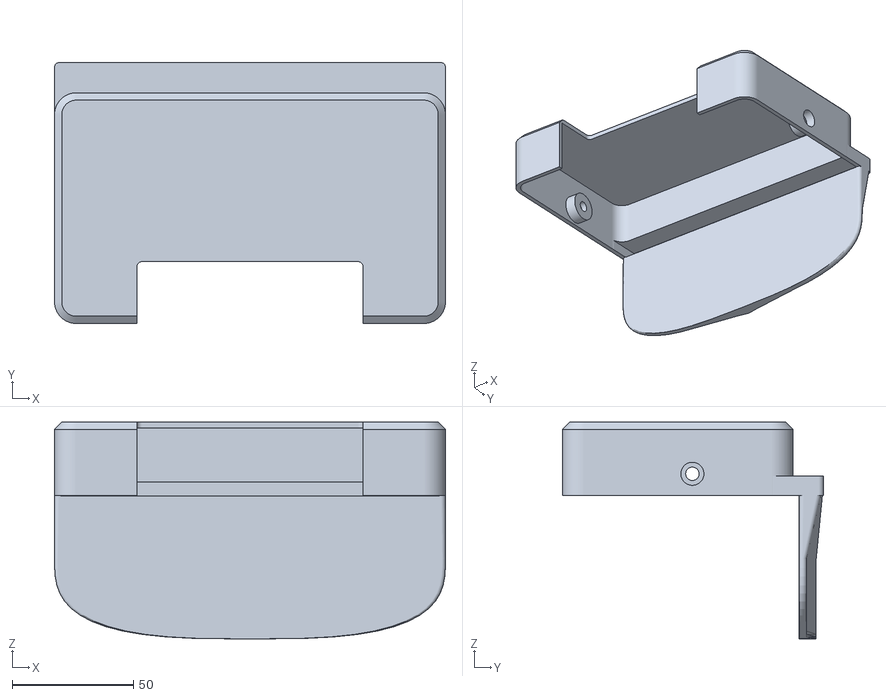
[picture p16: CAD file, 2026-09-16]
stl/gen4-cowl.stl
161.0 x 107.5 x 89.3

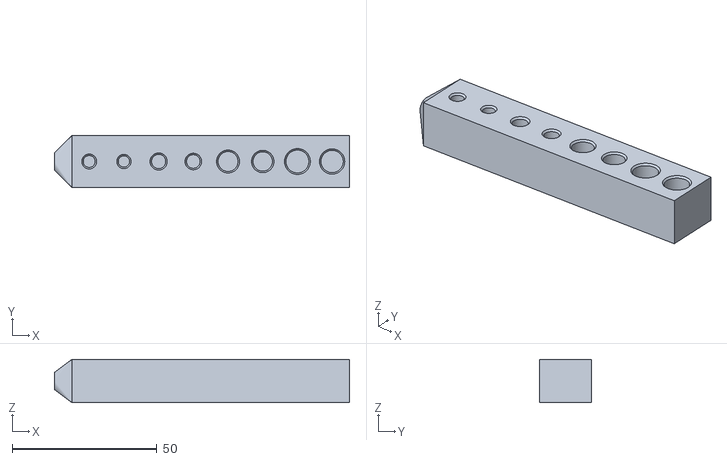
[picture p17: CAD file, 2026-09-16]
stl/gen4-insert-coupon.stl
102.0 x 18.0 x 15.0

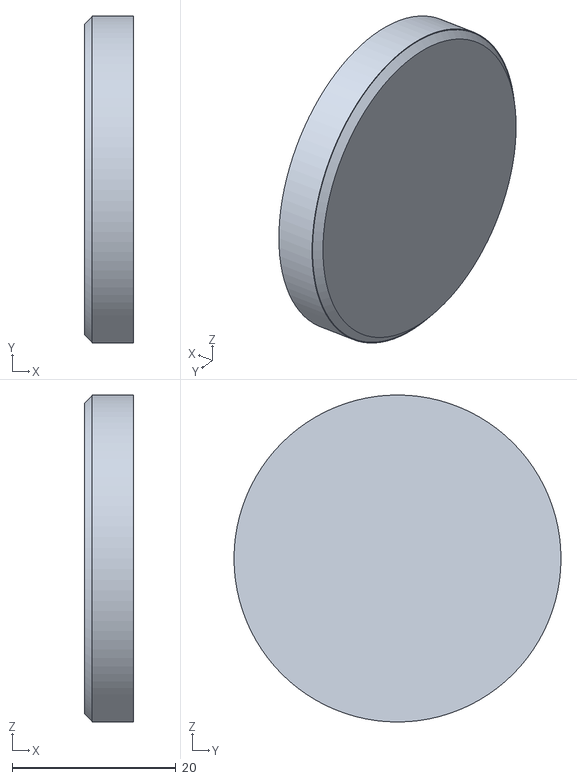
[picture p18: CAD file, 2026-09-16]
stl/gen4-pivot-puck-test.stl
6.00 x 40.0 x 40.0

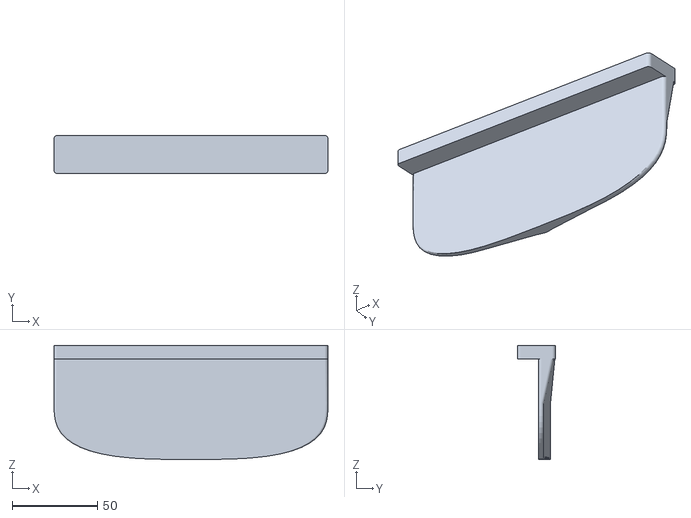
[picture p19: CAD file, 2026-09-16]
stl/gen4-brow-test.stl
161.0 x 22.5 x 67.0

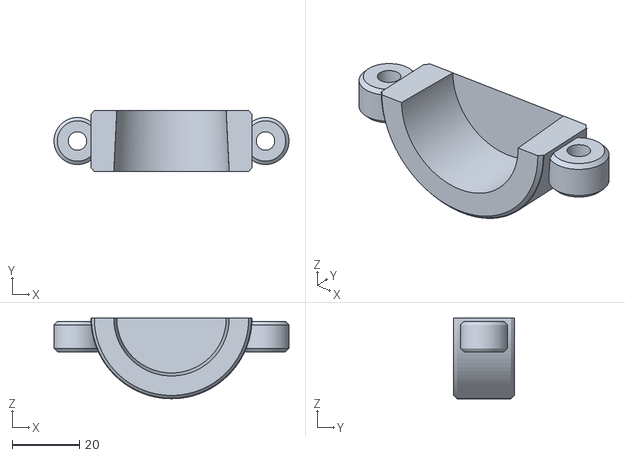
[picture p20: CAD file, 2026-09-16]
stl/gen4-cap.stl
70.0 x 18.2 x 24.0

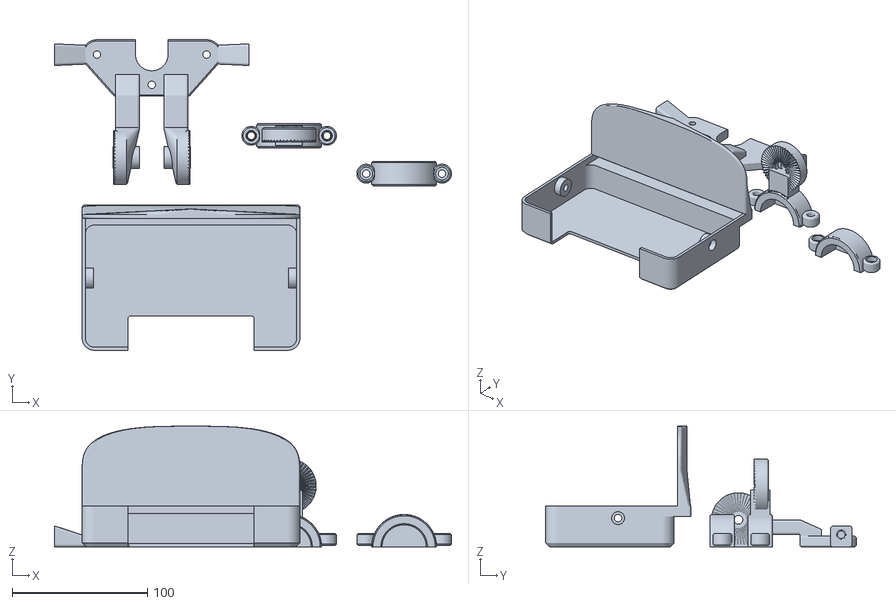
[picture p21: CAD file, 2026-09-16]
stl/gen4-plate.stl
293.4 x 229.6 x 89.3

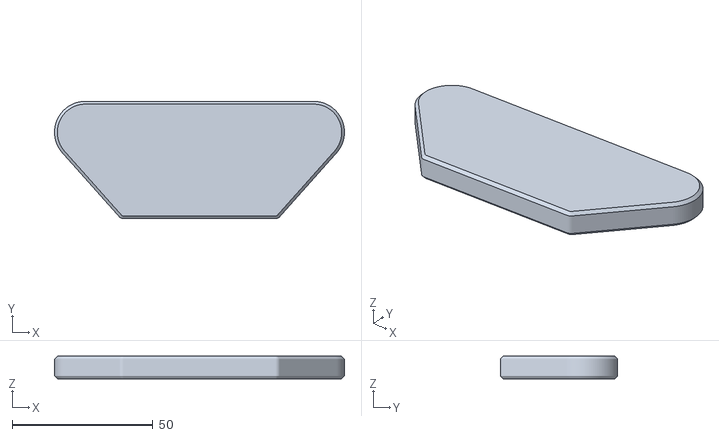
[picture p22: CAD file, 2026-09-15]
stl/gen4-yoke-plate-test.stl
103.0 x 41.7 x 8.00

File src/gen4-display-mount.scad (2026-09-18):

// ============================================================
//  Chaojie Gen 4 5" display (CJ-V5-04) — TWO-SIDED BAR MOUNT + REAR COWL
//
//  Design notes: docs/design-notes.md
//  Geometry: docs/display-geometry.md
//    — taken off the factory manual's §III installation drawing, rendered at
//      600 dpi and calibrated on its own printed dimensions (0.26% agreement).
//      Thread, depth and orientation confirmed on the unit 2026-09-13.
//
//  ⭐ TWO-CLAMP REWORK, 2026-09-15. The original design hung the whole display
//     off ONE narrow yoke arm, necking down through the cowl's opening to a
//     SINGLE spline disc and one clamp — a cantilever on a thin section, on a
//     vehicle with no drivetrain damping. Rejected by the owner: "we should be
//     attaching on both sides of the handlebars. There is a tiny sliver of
//     plastic supporting the entire display." Correct call. The bracket this
//     mount clamps to is 45mm wide; there are now TWO clamps, one butting each
//     of the bracket's two faces, joined by a cross-member that carries the
//     display and grows a spline boss on EACH side — a proper axle with a
//     spline at each end, not one disc taking the whole moment. Grip spreads
//     ~85mm along the bar (2x18mm clamps either side of the 45mm bracket)
//     instead of 18mm on one side of it, and the display centres itself
//     between the two pivots with no crank needed.
//  ⚠ LEFT SIDE OF THE BAR IS UNMEASURED — TEMPORARY VALUE. Only the RIGHT side
//     (docs/bike-fitment.md) was put under calipers. `bar_d0`/`bar_taper`/
//     `bar_run` are ASSUMED to mirror on the left (see the ⬜ flag at their
//     definition below). If the owner measures the left side and it differs,
//     the two clamps are NOT identical parts any more — split `bar_d0_l` etc.
//     out and re-print the left clamp against its own numbers before trusting
//     this mount on the road.
//
//  ⚠ THE TWO TRAPS. Both are forced by the display, not chosen. The assertions
//     below exist so that "simplifying" either one fails the render, loudly,
//     instead of failing on the bike.
//       1. The boot slot opens UPWARD. A downward slot cuts off the lone M5.
//       2. The pivot sits BELOW the housing. Any higher and the toothed face
//          covers the lone M5's head and the bolt can never be fitted.
//
//  ⚠ THE M5 THREADS ARE 5 mm DEEP — ONE BOLT DIAMETER. M5 x 12, no washer,
//     never longer. A bolt that bottoms feels tight and holds nothing.
//
//  PARTS:  gauge | yoke | arm | cap | cowl | brow_test | plate | spline_test |
//          pivot_puck_test | yoke_leg_test | yoke_plate_test | assembly |
//          pitch_probe_fixed | pitch_probe_arm
//  Export: openscad -o out.stl -D 'part="gauge"' gen4-display-mount.scad
//  ⚠ `arm`/`cap` are now a SHARED, SYMMETRIC clamp half — the same STL is
//     used on BOTH sides of the bracket (proof: docs/design-notes.md's
//     "why the clamp needs no left/right variant"). Print TWO of each. `yoke`
//     now carries a female spline at EACH end, mirrored about its own
//     vertical centreline, instead of one off to a side.
//  ⭐ PNG RENDERS DON'T NEED `--render`. Timed on spline_test: ~21s with
//     `--render 1` (forces the exact CGAL backend) vs ~0.3s with plain PNG
//     export (OpenCSG preview) — ~70x, visually identical for every part in
//     this file so far. A failed assert() still prints its ERROR line during
//     CSG-tree evaluation either way (that happens before either backend
//     runs), so the fast path keeps the loud-failure safety net. Use
//     `--render` only when you need the exact boolean result itself (e.g.
//     the mesh-proof STLs in spline-verification.md) — not for a batch of
//     inspection PNGs (Task 6).
// ============================================================

/* [DISPLAY — canonical, do not edit without changing docs/display-geometry.md too] */

/* [DISPLAY — OVERALL] the shell itself; the cowl is sized to match this */
disp_w        = 159.99;   // overall width
disp_h        =  93.98;   // overall height
disp_d        =  26;      // rear face -> glass. EXCLUDES the cable boot.
disp_corner_r =   9;      // the cowl reuses this so the two read as one object

/* [DISPLAY — HOLE PATTERN] the three M5s that carry the whole assembly.
   In doc coords: X from the left edge, Y DOWN from the top (docs/display-geometry.md). */
holes     = [ [ 39.50, 40.9 ], [ 120.50, 40.9 ], [ 80.00, 63.28 ] ];
hole_lone = holes[2];      // the unpaired M5, below the pair (confirmed on the
                           // unit 2026-09-13). Named so it is never re-derived
                           // by index elsewhere — if `holes` is ever reordered,
                           // only this line needs to change.
m5_depth  = 5;             // ⚠ usable thread. ONE bolt diameter. See assertions.
m5_head_d = 8.5;           // socket cap head
m5_len    = 12;            // ⚠ M5 x 12. Set by what the owner stocks (8/12/16/20
                           // — there is no M5 x 10 in the drawer, 2026-09-13) and
                           // by the 3-4 mm engagement window the 5 mm thread
                           // allows: bolt length minus part thickness must land
                           // in [3,4]. M5x12 pairs with 8 mm parts; M5x8 would
                           // have meant 5 mm parts. The assertions below are the
                           // real guard — change this and they will tell you what
                           // thickness it now demands.

/* [HEAT-SET THREADED INSERTS] --------------------------------------------
   ⭐ Added 2026-09-15, owner has a 380-piece M2..M8 kit and a 60W iron.

   ⭐ DIMENSIONS ARE FROM THE OWNER'S OWN KIT (photographed 2026-09-15), not
   from a generic table. Its sizing chart reads M2x3x3.2, M2.5x4x4, M3x4x4.2,
   M4x5x5, **M5x5x7**, M6x6x8, 1/4-20x6x8, M8x8x10 — i.e.
   **M<thread> x <length> x <OD>**. That reading is forced, not assumed: the
   alternative (OD then length) would put an M5 thread inside a Ø5 body and
   an M8 inside a Ø8, which cannot exist. So the M5s are **Ø7.0 x 5.0 long**.
   ⚠️ THESE ARE SHORT INSERTS — 5mm, about half the length of the generic
   9.5mm M5 this file first assumed. That is what sets ear_h and both bolt
   lengths below; a longer insert would need a deeper boss.
   ⬜ The OD is from the vendor's chart, not calipers. The **fit** (how much
   smaller the pocket is) is still unverified, so print `insert_coupon`
   (part="insert_coupon") before committing a real part: too big and the
   insert spins under torque, too small and it splits the boss.
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

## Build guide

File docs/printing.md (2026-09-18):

# Printing

## Material

**ASA.** The build rule is ASA / PC / PETG-CF and **never PLA**.

PLA creeps under sustained load and softens around 60 °C — a dark bracket in direct summer sun
reaches that, and it is carrying a screen on a moving vehicle. ASA earns its place twice over here:
it also does not go chalky under UV, which matters for a part living in the sun on the front of a
vehicle. PETG-CF is a good alternative if you want a flatter, more granular texture that hides layer
lines well; PC if you have the enclosure for it.

**The fit gauge is the exception** — print it in whatever is loaded. It is a bench check held against
the display for a minute and then thrown away. It never sees load, heat or UV.

## Orientation, per part

⭐ **Two-clamp mount (2026-09-15): print TWO of `arm` and TWO of `cap`, one clamp per side of the
bracket.** Both sides are the same STL — see `docs/design-notes.md` for why the part needs no
left/right variant.

| Part | Orientation | Why |
|---|---|---|
| `gauge` | flat, as exported | trivial |
| `yoke` | **bearing face on the bed** | that face must be flat and dimensionally true — it is what seats against the display. Now carries a spline at EACH end (mirrored) rather than one off to a side; the bearing face itself is unaffected by that. ⬜ **Spline orientation open** since the tilt-joint fix (`docs/design-notes.md`'s DM-6): each pivot boss faces sideways (its axis parallel to the bar), so with the bearing face down each Ø40 disc stands with its face vertical, a puck hanging off its own leg, rather than the flat "teeth as vertical walls off a horizontal disc" of the pre-fix geometry. Whether that needs support has not been slicer-checked |
| `arm` (×2) | ⭐ **LAID FLAT — clamp bore vertical** (rotate −90° about X in the slicer, or 'place on face' and pick the big flat side). 70 × 65 mm footprint, **18 mm tall** | ⚠️ **Changed 2026-09-16, after two prints in a row turned to spaghetti.** Standing upright it is a **65 mm tower on 262 mm² of bed contact** — 4 mm² per mm of height, where every other part in this repository is 11 to 515. Laid flat: **868 mm² of contact and 18 mm tall**, 2.8× the grip and a third of the height. Cost: two small islands (17 mm² each) start 2 mm up and want support. ⭐ It also settles the layer-direction question that was left open here — the rib's bending load now lies *within* the layer plane instead of across it, which is the stronger way to stack it |
| `cap` (×2) | ⭐ **LAID FLAT**, same rotation as the arm (−90° about X) | ⚠️ **Changed 2026-09-16.** Bore-side down it is 312 mm² on the bed (13 mm² per mm of height) with 593 mm² laid over air. Flat it is **868 mm² on the bed and only 223 mm² over air** — better on *both* counts, unlike the arm where flat costs some overhang. Its two ear bosses start 1 mm up either way; that gap is the clamp's pinch gap and is functional |
| `cowl` | **visible face down on a textured sheet** | ⭐ this is the whole reason the cowl is a separate part. The surface people see becomes one uniform moulded-looking texture rather than stacked layer lines. Ribs and bosses face up. Its bottom opening is now one symmetric notch (⭐ 2026-09-15) wide enough for both legs and both clamps |
| `insert_coupon` | flat, pockets facing up | throwaway; the pockets must print upward or their diameter is at the mercy of bridging |
| `brow_test` | **riser end on the bed, visor pointing up** — the same way up as the cowl | measured **0 mm² of overhang**, because the visor narrows all the way up. ⚠️ This used to say "flat", which is the **worst of the six axis-aligned orientations** (8874 mm² of steeply down-facing area). Footprint 161 × 22.5 mm, 67 mm tall — use a brim |

## Settings

Nothing exotic. Starting points:

- **Layer height** 0.2 mm for structural parts, **0.16 mm for the cowl** (it is the visible one).
- **Walls** 4 minimum on the yoke and arm; the cowl is designed around **2.4 mm = 6 perimeters at
  0.4 mm**, so set perimeters to match rather than letting infill do the work.
- **Infill** 40–50 % on yoke and arm (both clamp halves — print two of each). They are small parts and
  this is not where to save filament.
- **Supports** none required for any part in its stated orientation. If your slicer wants supports,
  the part is oriented wrong.
- **Brim** helps on ASA, which likes to lift.

## Supports — what was actually measured

⚠️ **This section used to claim every part prints unsupported. That was never measured.** What follows
is, for each part in its orientation above, the area of surface facing steeply downward (under 45° to
the bed) and not sitting on the plate, plus how high the highest such face sits.

| Part | Down-facing area | Highest | What it is |
|---|---|---|---|
| `gauge` | **0 mm²** | — | genuinely support-free |
| `insert_coupon` | 71 mm² | 1 mm | the chamfer on its own rounded end |
| `brow_test` | **0 mm²** | — | genuinely support-free, in the corrected orientation above |
| `cap` | 703 mm² (13 %) | 17 mm | mostly the clamp bore's own ceiling |
| `yoke` | 2946 mm² (11 %) | 36 mm | the two sideways spline pucks |
| `arm` | 1287 mm² (13 %) | 62 mm | the bore's ceiling, plus the sideways male spline disc |
| `cowl` | 5148 mm² (7 %) | 89 mm | the shell's internal ribs, bosses and side pads |

⚠️ **Down-facing is not the same as needs-support.** A horizontal bore's ceiling is self-supporting to
about 45° and then a short bridge, which is why the bore dominates the `arm`/`cap` figures without
being a problem. **Put each part through your own slicer and look at the support preview** before
committing filament — the table above is a geometric screen, not a slicer.

⚠️ **Bed size.** The yoke's footprint is **143.8 × 107.1 mm** — the largest single part. The cowl is
161.0 × 107.5 mm.

### ⚠️ ASA on a part this wide

The yoke is 144 mm across and the cowl 161 mm, both in a material that shrinks. Warping shows up at
the far corners first.

- **Enclosure, and no draught.** This is the single biggest factor for ASA.
- **Bed 100–110 °C**, and clean it — ASA lifts off residue long before it lifts off glass.
- **Fan off, or under 20 %.** ASA warps and delaminates with high fan. Only bridge and overhang fan
  should ever go above that.
- **Brim, 8–10 mm.** Cheap insurance on both wide parts.
- Slow the first layer and give it a little extra squish.

### ⛔ The cowl and the yoke REQUIRE support — turn it on

**The cowl is the worst of the set**, despite having the best bed adhesion (11807 mm²). Measured:
**4472 mm² laid over air**, dominated by a single **2092 mm² region that begins 22.4 mm up** — the sun
visor's riser, which is full-width and reaches 12.5 mm beyond the box's own top edge, so it appears in
mid-air — followed by **1183 mm² more at 30.4 mm** as the visor carries on past the front rim. Nothing
sits under either, all the way down to the bed, so **support on build plate only** reaches them.

### ⛔ The yoke REQUIRES support — turn it on

Measured with `tools/check_print.py`: **2171 mm² of the yoke is laid over air**, including two
**390 mm² patches 9.2 mm up**, where each leg begins a 45 mm horizontal cantilever out to its pivot.

⭐ **The pivot discs now land on a flat** (2026-09-16). They used to stand on their own mathematical
tangent — `yoke_standoff` had been set to bring the Ø40 disc's lowest point to *exactly* z=0, which
avoided clipping the bed and created the worst possible first layer: a 40 mm disc balanced on a line,
the two of them sharing 184 mm² of contact. A small foot now fills the sliver between bed and arc, so
each disc lands on a real **20 × 6 mm flat**: contact at that end went **184 → 317 mm²**.
⛔ **The foot stops at the female spline's root plane.** A first version ran the full disc
stack and filled the tooth valleys over about 40° — the yoke read x=28.45 in the bottom sector
where every other angle reads 26.75 — so the male teeth had nowhere to go. A print aid that
blocks the joint it is printed for is not an aid.

Use **support on build plate only** (everything needing it sits over bare bed), and keep a brim.
Without support those legs droop, and the drooped material is what the nozzle then catches.

### ⚠️ Curling edges, and the nozzle knocking the part

The yoke is the widest flat part here — a 144 mm bearing plate in a material that shrinks. Corners lift
first, then the nozzle strikes the raised edge and walks the part off the bed.

- **Fan off for the first 3–5 layers, then 20 % maximum.** A PLA profile at 100 % fan will curl ASA on
  its own, and this is the most common single cause.
- **Enclosure, lid shut, no draught** — passive 40–50 °C in the chamber is enough.
- **Bed 100–110 °C, held all print.** Clean it with IPA; ASA lifts off finger oil long before glass.
- **Brim 10–15 mm, OUTER ONLY.** The yoke's first layer is **three separate islands** — the plate
  and its ears at 3512 mm², and the two pivot feet at **183.7 mm² each**, alone out at (±23, −70). An
  outer brim rings all three, which is what those two small ones need. ⛔ **Not inner or both**: the
  only holes in that layer are the three M5 clearance holes, so an inner brim just fills the bolt
  holes with material you then have to pick out.
- **Z-hop 0.2–0.4 mm on travel.** This does not stop curling, but it stops the nozzle *hitting* what
  has curled — which is the difference between a blemish and a part on the floor.
- First layer slower, nozzle +10 °C, a little extra squish.
- ⚠️ **Do not halve your speeds to fix this.** Slower means each layer has longer to cool and contract
  before the next one lands on it, which makes ASA curl slightly **worse** — and it doubles what a
  failure costs you. Moderate speed in a warm chamber beats slow speed in a cold one.

⭐ **The yoke's cowl-fixing ears used to lift, and that was the model's fault, not a setting.** Their
undersides sat 0.8–2.4 mm above the bed, sloping only 5° — a 21 mm unsupported shelf per side at the
part's outermost corners, which is where shrinkage pulls hardest. They now sit **coplanar with the
bearing face**, flat on the bed: the part's footprint reaches its full ±71.9 mm, bed contact went from
3133 to **3745 mm²**, and no column of either ear begins in mid-air. If you are printing an older
export and see them curl, that is why.

⬜ **Not slicer-checked.** The `yoke` and `arm` spline orientations have been an open question since
the tilt-axis fix (each pivot boss now faces sideways, so its Ø40 disc stands with its face vertical).
These numbers say the question is real rather than theoretical.

**Why the orientations are what they are**, where the answer is not "least overhang":
- `cowl` — **surface finish wins.** Laying it on its side nearly halves the down-facing area
  (2843 mm²) but puts the one surface people actually see against a support interface. Not worth it.
- `yoke` — **the bearing face must be flat and dimensionally true**; it is what seats against the
  display. Standing the yoke on edge is marginally better on overhang (1993 mm²) and worse at the job.
- `arm` — the six axis orientations span 1093–1413 mm², i.e. nothing to choose between them on
  overhang. ⬜ **Layer direction is the better argument and has not been settled:** bore-side down puts
  the layers perpendicular to the bending load in the clamp→spline rib, which is the weakest way to
  stack them. If a printed arm ever fails, it will fail there, and re-orienting is the first thing to
  try.

If you re-orient something for your own reasons, check the overhangs yourself — the model does not
enforce print orientation.

## Print in this order

The order exists to catch mistakes cheaply. Do not skip ahead.

0. **`insert_coupon`** — eight pockets, two fits each for M3/M4/M5/M6, all 13 mm deep so only the
   diameter is under test. Press one insert of each size in and find which pocket seats square and
   flush without bulging the boss. ⚠️ **The chamfered end is M3**, and the order from there is
   M3−0.1, M3−0.3, M4−0.1, M4−0.3, M5−0.1, M5−0.3, M6−0.1, M6−0.3. Then set `insert_fit` (and
   `insert_m5_od` if your inserts differ from the kit's Ø7 × 5) and re-export. Minutes to print.
1. **`gauge`** — proves the hole pattern, the slot, the flat-band assumption and your bolt length
   against the real display. Short print. Everything downstream inherits that hole pattern, so if it
   is wrong you want to know now.
2. **`brow_test`** — the riser and visor alone; 0 mm² of overhang, no supports. Confirms the visor's reach and shape against the
   real screen, seated normally, before the cowl's shape is committed. ⚠️ Check both things it can get
   wrong: that it shades the screen in sun, **and** that it does not cut into the top of the screen
   from your own riding position (`docs/design-notes.md`, "The underside is flat on purpose").
3. **`yoke`**
4. **`arm`** + **`cap`**, **×2 each** — needs your handlebar diameter measured **on both sides** first
   (`docs/bike-fitment.md` — the left side is a temporary assumption until confirmed). Print one pair,
   confirm it clamps and mates its spline correctly, before committing filament to the second.
5. **`cowl`** — last, because it is the only part whose shape depends on all the others being settled.

## Building the STLs yourself

Pre-built STLs are in [`stl/`](../stl). To regenerate them, or to build after changing a parameter:

```bash
./tools/build.sh
```

That exports every part and checks each exported bounding box. It needs OpenSCAD on `PATH`.

> ⚠️ **OpenSCAD gotcha, if you script around this.** A failed `assert()` still **exits 0** when
> exporting a "tree" format (`echo`, `csg`, `ast`, `term`). It only returns non-zero for a **solid**
> format (`stl`, `off`, `3mf`, `amf`). So an assertion checked with the wrong export format silently
> reports success. `build.sh` exports solid formats for exactly this reason. **PNG renders never catch
> assertion failures** — do not rely on a render alone as a check.
>
> Related: `openscad -o /dev/null` fails for *any* `.scad` file, because `/dev/null` has no extension
> to infer a format from. Pass `--export-format=asciistl`.

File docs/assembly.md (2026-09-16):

# Assembly

## Hardware you need

| Where | Part | Note |
|---|---|---|
| Display → yoke | **3 × M5 × 12** socket cap | ⚠️ **no washer, never longer** — see below |
| Pivot | **2 × M6 × 35** + nyloc + plain washer | one per side. ⛔ **not an insert** — see `docs/design-notes.md`. 26.0 mm of grip, 7.3 mm into the nut |
| Bar clamp | **4 × M5 × 16** + **4 × M5 heat-set inserts** | 2 per clamp, and there are two clamps. Inserts go in the **arm's** ears, from the top. No nuts |
| Cowl → yoke | **2 × M5 × 12** + **2 × M5 heat-set inserts** | inserts go in the **yoke's side ears**. Heads recess into the cowl's side walls |
| Heat-set inserts | **6 × M5 (Ø7 × 5 long)** | 4 across the two arms, 2 in the yoke. ⬜ print `insert_coupon` first and confirm the pocket fit |
| Clamp bore | a strip of **inner-tube rubber** | protects the bar and takes up ovality |

Medium-strength threadlocker for the three display bolts.

If you print the parts at a different thickness, **recompute the bolt length**: length minus part
thickness must land in 3–4 mm. The model asserts this, so change `yoke_t` and it will tell you what
`m5_len` it now demands, or refuse to render.

---

## ⚠️ The one that bites: 5 mm of thread

The display's inserts give **5 mm of usable thread — one bolt diameter.** With 8 mm parts and M5 × 12
you get **4 mm engaged and 1 mm of air**.

- **Never fit a longer bolt.** M5 × 16 into an 8 mm part bottoms out.
- **Never add a washer under the head.** It eats engagement you do not have.
- **Run each bolt down by hand first** and confirm it pulls the yoke tight rather than stopping
  against the bottom of the hole. **A bolt that bottoms feels tight and is holding nothing.**
- **Modest torque, spread over three points.** Threadlocker is doing the retention work here, not
  clamp force.

---

## Order

1. **Fit the yoke to the display.** Slide it on so the cable boot passes up the slot, then bring it
   down until the three holes line up. The loom stays *behind* the yoke — nothing threads through
   the slot.
2. **Three M5 × 12, by hand, then threadlocker, then modest torque.** Check each pulls tight.
3. **Clamp the arm to the handlebar.** Rubber strip in the bore first. Snug the two clamp bolts
   evenly so the gap stays parallel — do not close one side first.
4. **Join the spline, both sides.** Choose your angle, mesh the teeth, and run an **M6 × 35** through
   from the clamp side with a **plain washer under the nyloc** — the nut turns against printed ASA and
   its corners dig in without one. The bolt enters a counterbored seat in the arm's tip puck and lands
   on a flat pad on the yoke leg's inboard face. The teeth carry
   the load, so this bolt only needs to hold them together — it is not a friction joint and does not
   want to be cranked.
5. **Route the loom** down behind the arm, leaving a service loop so the bars can reach full lock
   without tugging the connectors.
6. **Fit the cowl last.** Hook the top lip over the display's top edge first, rotate the cowl down,
   then drive one **M5 × 12** in through each side wall into the yoke's ear. The heads recess below
   the side face; nothing shows on the back.

**Press the inserts before any assembly.** Six M5s: two in each clamp arm, in the top face of each
ear — and there are two arms — plus one in each of the yoke's two side ears, from the outer face. Iron at ~240 °C for ASA,
straight and slow, and let it cool before loading the thread. ⬜ **Print `insert_coupon` first** —
insert fit is the one dimension in this project that depends on your supplier rather than on the
display, and a pocket that is 0.2 mm out either spins or splits.

**Service order is the reverse:** cowl → arm → yoke. The lone M5's head is clear, but the arm must
come off before the yoke can.

---

## Before you ride

- ⚠️ **Check the bars reach full lock** without the display fouling the frame, the tank, your hands,
  or the loom pulling tight.
- ⚠️ **Proof-load it on the bench** before trusting it — hang the display and shake it hard.
- **Re-check every fastener after the first ride.** Vibration finds everything.
- A paint witness line across each bolt head and the part makes any movement visible at a glance.

---

## Setting the angle later

The spline is **7.5° steps**, 48 teeth. Slacken the M6, lift the faces apart, rotate, re-mesh,
re-tighten. You do not need to touch the display bolts or the bar clamp.

Once you have ridden it enough to know the angle you want, you can print the joint **solid** — set
`teeth = false` and re-export the yoke and arm. Same file, same geometry, no teeth and nothing to
loosen.

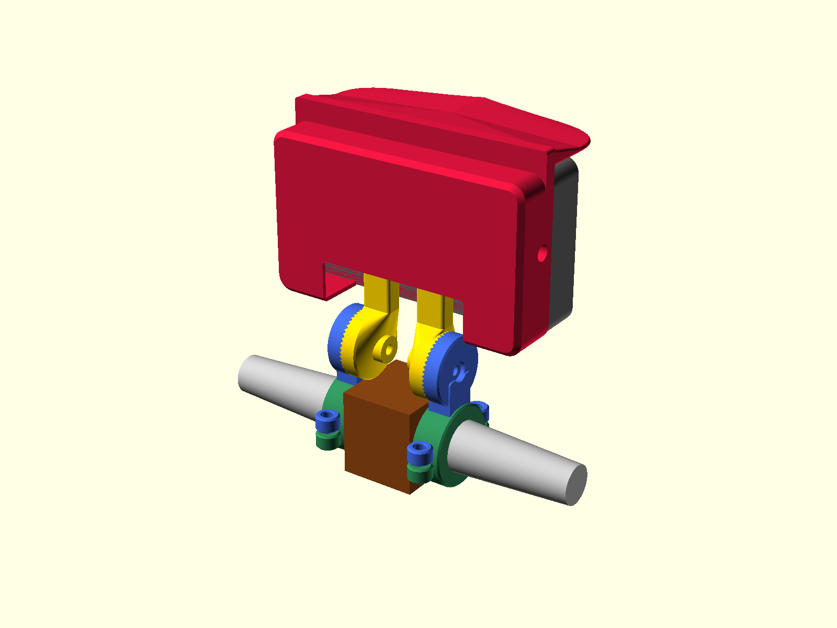
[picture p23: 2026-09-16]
renders/gen4-assembly-iso.png

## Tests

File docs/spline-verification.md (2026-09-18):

# Face spline mesh verification — bench note

Backs the comments in `gen4-display-mount.scad`'s `face_spline()`. Read this before
touching the tooth geometry or before trusting any `intersection()` result on it —
both the construction and the verification method have a documented failure mode
below, and re-deriving either one from scratch is exactly the expensive mistake
this note exists to prevent. §7 documents a third: the un-fixed construction
exported a non-manifold mesh (0 holes, but edges shared by >2 faces) that made
every part unusable with `tools/check_fit.py`. §8 documents a fourth, found
only after §7 closed: the teeth were watertight and manifold but almost
entirely HOLLOW — a thin shell following the ramp's surface with no material
filling the gap down to the disc. Manifold-ness says nothing about solid fill;
neither defect's checks would have caught the other.

All numbers below are from the shipped module (`spline_od=40, spline_id=12,
spline_n=48, spline_h=1.6`), re-measured against the current file, not transcribed
from an earlier draft.

⭐ **Two-clamp rework (2026-09-15): this whole note applies unchanged, to BOTH joints.** The yoke now
carries a female spline at each end of the hinge axis (`pivot_x_r`/`pivot_x_l = -pivot_x_r`), each
mating its own clamp's male half, instead of one female spline at the centre. The RIGHT joint is
bit-for-bit the same construction this note already proves (`base_male=3`, `base_female=3`, §6's own
seating figures apply directly, unchanged). The LEFT joint is `mirror([1,0,0])` of the entire right
one — spline, puck, leg and seated clamp together, not a second construction — and mirroring is an
isometry (it preserves every distance), so every contact/gap number in §5/§6 carries over to the left
joint exactly, without re-running the rod probe there: a mirrored copy of a "0.0034mm real contact"
scene is still a "0.0034mm real contact" scene, just reflected. See `docs/design-notes.md` for why the
mirror also reproduces the correct tooth PHASE (the male spline's own pattern, phase=0, is
self-symmetric under this exact mirror) rather than an accidentally-misaligned one — that argument,
not a fresh measurement, is what licenses skipping a second full rod-probe run on the left joint.

## 1. The single-hull tooth doesn't mesh — measured, not assumed

The first construction built one flank as `hull()` of 6 points: the two trough
corners (at `spline_id/2` and `spline_od/2`, at the tooth's angular edge) and the
peak point (at both radii, at the tooth's centre angle). This looks right in a
render — even, radial, meeting at the bore — but a render only shows the
silhouette, not whether the height at a given angle is independent of radius,
which is what two mating faces actually need.

Probing the solid with a thin (0.02mm) vertical rod at several radii and the same
angular fraction across one flank showed the height BOWS with radius:

| angular fraction (0=peak, 1=trough) | r=6.5 | r=13.0 | r=19.9 | ideal (linear) |
|---|---|---|---|---|
| 0.25 | 1.34 | 1.35 | 1.21 | 1.20 |
| 0.50 | 0.91 | 1.09 | 0.82 | 0.80 |
| 0.75 | 0.47 | 0.83 | 0.42 | 0.40 |

Worst deviation from "height independent of radius": **0.43mm at r=13
(mid-radius), fraction 0.75**. Cause: `hull()` joins the trough point at
`spline_id/2` to the trough point at `spline_od/2` with a straight CARTESIAN
edge, not a constant-radius arc — that chord dips inboard of the true circle
between its ends, and the resulting flank is a warped (non-planar) ruled surface,
not the flat "height = f(theta) only" ramp the meshing argument needs. Mated
against a correctly-phased partner this bow showed up as ~330mm³ of real
interference at the design distance (measured on the pre-fix construction) — not
the near-zero a provably-meshing joint needs.

(An even earlier idea, `linear_extrude(scale=...)` of one radial cross-section,
was rejected without needing measurement: `scale` shrinks both plan axes toward
the centroid as it extrudes, so a ridge meant to span the full
`spline_id/2..spline_od/2` radius collapses toward a point at full height —
a starburst of spikes meeting near the bore, not radial ridges reaching the tip.)

## 2. The fix: chain short hulls instead of one long one

Each flank is now walked in `nseg=8` steps from trough to peak (16 short hulls
per tooth, 768 for the whole ring). Every sample's height comes from the exact
triangular-wave formula, not from interpolating the previous hull, and each pair
of adjacent samples becomes its own short `hull()` of 4 points (2 radii x 2
angles). Shrinking the angle per chord shrinks its inboard dip much faster than
linearly, so a modest `nseg` gets the bow down to a fraction of a millimetre
(numbers in §4). Raise `nseg` if a future `spline_n`/`spline_od` combination (a
longer chord per segment) reopens a measurable gap.

## 3. The whole-ring `intersection()` is not a trustworthy mesh test

The obvious verification — `intersection(){ male_face; female_face; }` on the
full 48-tooth rings — gives answers that contradict direct measurement at the
same relative pose. Reproduced against the shipped module:

```
male   = face_spline(male=true,  base=3)
female = translate([0,0,seat]) mirror([0,0,1]) face_spline(male=false, base=3)
   where seat = base + base + spline_h = 7.6
```

| scene | `intersection()` volume | CGAL `Volumes:` | rod probe at θ=0 (0.02mm rod, r=19.9) |
|---|---|---|---|
| correctly seated | 44.38 mm³ | 2 | 0.013 mm (real, small contact) |
| rotated a half tooth pitch (deliberately misaligned, peak-on-peak) | **0.0058 mm³** | **193** (≈192 disjoint fragments + 1 exterior) | **1.601 mm** (full-depth collision) |

The misaligned row is the damning one: a single point on the ring already
measures 1.601mm of unambiguous, full-depth collision (male's peak driven
1.601mm into female's peak — nowhere near touching, let alone meshing), yet the
whole-ring boolean reports 0.0058mm³ total across all 48 teeth. That is at least
three orders of magnitude too small to be consistent with even ONE tooth
colliding this hard, and the `Volumes: 193` fingerprint (versus the expected
single connected interference region, or 48 separated ones) shows CGAL's Nef
polyhedron boolean shattering the result into ~192 near-degenerate fragments
instead of computing it — it has lost its footing, not found a small answer.
This is CGAL/OpenSCAD running out of numerical robustness on two operands that
are each already hundreds of thin, near-touching convex pieces (every `hull()`
segment from §2, on both sides at once), not a defect in the modelled solid.

The "correctly seated" row's 44.38mm³ happens to be the right order of magnitude
(a ~0.01-0.03mm contact spread over the ~1144mm² teeth annulus is ballpark
10-35mm³) but should NOT be read as a precise figure either, for the same
reason — a whole-ring boolean on this geometry is not a instrument to trust,
even when its answer looks plausible.

**Conclusion: verify this geometry by intersecting each face separately against
a small probe (a thin rod, or a small region), then compare the two resulting
z-ranges arithmetically — never by booleaning the two complex faces directly
against each other.** Every rod-probe number in this note was cross-checked
this way across dozens of points during development and never once disagreed
with hand-derived geometry; the whole-face boolean disagreed with it twice
(the case above, and a smaller-scale version restricted to 5 teeth instead of
48, ruling out "just needs simpler geometry" as the fix).

⚠️ **This is not a CGAL-specific problem — `tools/check_fit.py intersect`
(manifold3d, a different engine entirely) fails the SAME way on a whole
spline ring**, confirmed 2026-09-14: 42.75mm³ for a correctly-seated pair
and 0.0058mm³ for a deliberately misaligned one — backwards, since a
misaligned (peak-on-peak) pair should report the larger volume by a wide
margin (§5's own numbers put a single point's collision at 1.6mm deep) and
seated should be closest to zero. Same root cause as CGAL's failure above:
both operands are already hundreds of thin, near-touching convex `hull()`
pieces, and that defeats a general-purpose exact boolean regardless of
which library computes it. `check_fit.py` remains the right tool for
whole-part clearance checks (arm vs. yoke, say) — just never `intersect`
on two whole spline rings against each other. The rod probe (§4) is the
only method proven trustworthy on this specific geometry.

## 4. The rod-probe method, in enough detail to re-run

⚠️ **The redeclaration line below is load-bearing — do not delete it as boilerplate.**
`use <>` imports **modules and functions only, never top-level variables.** They are *not* inherited
from the file above. Drop that line and `spline_h` becomes `undef`, so `seat` becomes `undef`, and
`translate([0, 0, undef])` **silently coerces to `translate([0, 0, 0])`** — OpenSCAD emits a
`WARNING`, not an error, and every z-value below comes out wrong while the script appears to run.
A reviewer reproducing this method hit exactly that and got a plausible-looking wrong answer.

(The reverse is also true and worth knowing: these redeclarations cannot *override* the constants
`face_spline()` itself uses — it reads its own file's values. They exist only so this wrapper can
compute `seat`.)

```openscad
use <gen4-display-mount.scad>
// ⚠ Required. See the note above — `use` does not import variables.
spline_od = 40; spline_id = 12; spline_n = 48; spline_h = 1.6; teeth = true; eps = 0.1;

base = 3;                              // or whatever the caller under test uses
seat = base + base + spline_h;         // general: base_male + base_female + spline_h

module male() { face_spline(male = true, base = base); }
module female_mated(extra_rot = 0, dz = 0) {
  translate([0, 0, seat + dz])
    mirror([0, 0, 1])
    rotate([0, 0, extra_rot])
    face_spline(male = false, base = base);
}
// thin probe — 0.02mm dia. A fatter rod (0.3mm was tried) smears across enough
// angle near a peak/trough to inflate the reading by an order of magnitude —
// confirmed by re-measuring the same points with both diameters; this is why
// the diameter is called out explicitly rather than left to "whatever's handy".
module rod(r, theta_deg) {
  translate([r*cos(theta_deg), r*sin(theta_deg), -5])
    cylinder(d = 0.02, h = 20, $fn = 6);
}

// Probe each side SEPARATELY against the rod (two simple, reliable 2-way
// booleans), not against each other:
intersection() { male();              rod(19.9, THETA); }   // -> male_top
intersection() { female_mated(0, 0);  rod(19.9, THETA); }   // -> female_bottom
```

Read each result's z-range with `tools/check_stl.py` (or, for more than 2
decimal places, `check_stl.read_stl()` directly — the printed 2-decimal figures
round differently enough at this scale to matter). Overlap at that θ =
`male_top - female_bottom`; positive means contact/interference, and OpenSCAD
refusing to write an STL at all (empty top-level object) means a true physical
gap there.

⚠️ **Probe by calling the module directly — never by `import()`ing an already-
exported STL.** Re-importing `gen4-yoke.stl` (or any part's own export) and
intersecting it against a probe gives a FALSE EMPTY (verified,
2026-09-13): OpenSCAD prints `ERROR: The given mesh is not closed! Unable
to convert to CGAL_Nef_Polyhedron.` to stderr, then reports the top-level
object empty and exits non-zero — the error line IS there to `grep`, but
it is easy to miss if the check is written the way every other probe in
this file is (`grep -iE "empty|error"` then treat "no STL written" as the
proof passing): that pattern reads this failure as a clean, genuine
clearance result, not a boolean CGAL refused to even attempt. The part's
own `.stl` export is watertight by every check this file uses
(`check_stl.py`'s bbox, `Volumes:`, and the union-find connected-component
check); it is specifically the round-trip through `import()` that produces
a mesh CGAL won't boolean against. Every proof in Tasks 3+ intersects the
live module (`yoke()`, `arm()`, …) called
straight out of `gen4-display-mount.scad`, never a re-imported mesh — keep
doing that for Tasks 4–6's own probes too.

## 5. Corrected seated / misaligned table

Re-measured with the 0.02mm rod against the shipped module, `base=3` both
sides, `r=19.9`, after the §7 trough-pullback fix (numbers below are
POST-fix; §7 explains why the trough (±3.75) and peak (0) columns moved a
little from the pre-fix figures while the quarter points did not):

| θ (deg) | correctly seated — overlap | rotated half a pitch — overlap |
|---|---|---|
| -3.75 (male trough / female peak) | 0.0038 mm (contact) | **-1.5934 mm** (true gap) |
| -1.875 (quarter point) | 0.0258 mm (contact) | 0.0257 mm (touching only) |
| 0 (male peak / female trough) | 0.0034 mm (contact) | **1.6010 mm** (full-depth collision) |
| +1.875 (quarter point) | 0.0258 mm (contact) | 0.0257 mm (touching only) |
| +3.75 (male trough / female peak) | 0.0038 mm (contact) | **-1.5934 mm** (true gap) |

Reading this: correctly seated, the two faces are in real, small
(0.004-0.026mm) contact everywhere sampled around a full pitch — not floating
with a gap, and not colliding hard; the whole ramp is a matched (conjugate)
pair, touching along its full flank rather than only at the peak/trough
extremes. A half-pitch misalignment produces the opposite signature: a full
1.6mm collision exactly where peaks now land on peaks, and a true ~1.6mm gap
exactly where troughs now land on troughs. The two scenes are unambiguously
different, and the "correctly seated" numbers are comfortably below anything
an FDM printer resolves (a 0.4mm nozzle, 0.2mm layers) — a print will fuse
this contact seamlessly rather than leave a visible gap or force the two
faces apart.

## 6. What the shipped yoke actually calls, and what that means for the arm

⚠️ **This section previously verified `base_female=8` ("the real value Task 3's
yoke will use, `yoke_t`") — that never shipped.** The yoke's female half is
`face_spline(male=false, base=3)`, called from a pedestal built up on the
arm's own tip stack (`yoke_tip_h`, `yoke_standoff` — see
`gen4-display-mount.scad`'s own comments), not laid straight onto the 8mm
bearing plate. The spline's base is decoupled from `yoke_t` on purpose: the
plate's own thickness is sized for M5 thread engagement (§ DESIGN — YOKE's
own `yoke_t` comment), the spline pedestal for a compact, printable boss at
the pivot — nothing requires the two to match, and forcing them to would
mean an 8mm-tall boss with no structural reason to be that deep. **`base=3`
is the number to build against, not `yoke_t`.**

Re-verified with the pair that actually exists in this codebase today —
`base_male=3` (`spline_test`'s own demo instance, the only male call in the
file so far) and `base_female=3` (the yoke's real value) — using §4's method
against the shipped module, not transcribed from §5:

```
seat = base_male + base_female + spline_h = 3 + 3 + 1.6 = 7.6
male_top(θ=0)     [z-range 0.0 .. 4.6005]     = 4.6005
female_bottom(θ=0) [z-range 4.59710 .. 7.6]   = 4.59710
overlap = 4.6005 - 4.59710 = 0.0034 mm
```

Small, real, correctly-signed contact — consistent with (and, since this is
literally the `base=3/base=3` case, numerically matching) §5's own θ=0 row
(0.0034mm). `male_top` is bit-for-bit the same value as before §7's fix
(θ=0 is the centre of a tooth's peak, an interior sample the fix never
touches); `female_bottom` moved from 4.58722 to 4.59710 because, at this
θ, the female half is at ITS OWN trough (its phase is half a pitch from the
male's), which is exactly the vertex §7's fix pulls back — still a small,
real, positive-contact number, just not bit-identical to the pre-fix one.

**What Task 4's arm therefore needs:** its own male base is a free choice —
the formula holds for any `base_male`, proven independently in the original
version of this section with `base_male=3, base_female=8` — but whatever
value the arm picks, it must compute `seat` against the female's REAL base
(**3**, read from `gen4-display-mount.scad`'s `yoke()`, not assumed to be
`yoke_t`), and should re-run this section's method against both shipped
modules once the arm exists, the same way this update did.

## 7. The non-manifold defect, and the trough-pullback fix

Found after Task 2 closed, by a checker that didn't exist then
(`tools/check_fit.py`, which refuses to answer on a non-watertight mesh —
see its own header for why). Measured with trimesh (`mesh.is_watertight`
and an edge-face-count pass: an edge shared by more than 2 faces is
non-manifold):

| part | faces | boundary edges (1 face) | non-manifold edges (>2 faces) | watertight |
|---|---|---|---|---|
| `spline_test`, `teeth=false` | 768 | 0 | 0 | **True** |
| `spline_test`, `spline_n=12` | 5864 | 0 | 11 | False |
| `spline_test`, `spline_n=48` | 16560 | 0 | 80 | False |
| `yoke` | 21578 | 0 | 54 | False |

Zero boundary edges rules out a hole (`fill_holes()` found nothing to fill);
the count scaling with tooth count, and `teeth=false` alone being clean,
both point at the teeth specifically, not the disc or the bore.

### Isolating the junction, not guessing it

`tooth()` builds each flank as a chain of `nseg=8` short `hull()`s (16 per
tooth). There are two candidate junctions: adjacent segments *within* one
tooth's own chain, and adjacent *teeth* meeting at the shared trough. Built
each in isolation (no cylinder, no bore, just the raw union) and measured:

| construction | faces | watertight | non-manifold edges |
|---|---|---|---|
| 2 adjacent segments, one flank | 56 | True | 0 |
| 1 whole tooth (all 16 segments) | 280 | True | 0 |
| 1 tooth + the base disc | 692 | True | 0 |
| 2 adjacent teeth, no disc | 590 | **False** | **1** |
| full ring (48 teeth), no disc | 14896 | **False** | **82** |

The intra-tooth chain is clean at every step (proven twice: 2 segments
alone, and the whole 16-segment tooth), and a tooth resting on the disc is
clean too. Only two *separate* `tooth()` instances meeting each other
reproduce the defect — 1 non-manifold edge per adjacent pair, ~82 for a
48-tooth ring, matching the shipped part's 80 (the small gap between 82 and
80 is the disc changing the local mesh slightly; it doesn't change which
junction is at fault). Inspecting the actual non-manifold edge in the
2-tooth case placed it exactly at the trough vertex (r=spline_od/2, the
outer radius, at the shared boundary angle) where 4 faces meet instead of 2.

**Root cause:** every tooth is the same `tooth()` reached through a
different `rotate([0,0,i*step+phase])`. Tooth *i*'s own last sample and
tooth *i+1*'s own first sample are meant to be the identical point
(`i*step+phase+half` on one side equals `(i+1)*step+phase-half` on the
other, algebraically) — but each is reached via a *different* `rotate()`
call, hence a different floating-point path to "the same" angle. CGAL's
exact arithmetic sees two near- but not bit-identical faces meeting exactly
face-to-face and leaves a degenerate seam instead of merging them, exactly
the "adjacent solids meeting exactly face-to-face" signature this file's
own CLAUDE.md-equivalent warning describes for CGAL booleans elsewhere.

### Two fixes tried and rejected

- **Extend each tooth past ±half to overlap the neighbour's first chord**,
  using the wrapped triangular-wave formula so the extension's height
  matches the neighbour's real geometry exactly (a deliberate duplicate).
  Made it WORSE: 4 non-manifold edges on the 2-tooth isolation, up from 1.
  Two independently-rotated, near-duplicate surfaces crossing each other
  throughout a whole overlap band gives CGAL more disagreement to resolve,
  not less.
- **Enlarge the shared boundary vertex into a small cube** (a marker big
  enough to swamp the floating-point gap between the two rotate() paths).
  Same failure, same reason: still two independently-rotated near-duplicate
  solids, just bigger ones, at spline_n=48 giving 81 non-manifold edges —
  no better than the original 80.

### The fix that works: pull the trough vertex back, don't extend it

Rather than making the two teeth's boundary geometry cross or duplicate,
stop each tooth a small angle short of the shared boundary so the two
neighbours never place a vertex at the same spot at all. Only the `k =
±nseg` sample (the trough end of each flank) moves; its *height* stays
exactly 0, so the tooth still touches the disc (still one connected body —
checked by counting connected components, not just `is_watertight`: an
early version of this fix changed the trough's height too and silently
detached every tooth from the disc into its own floating island, 13
separate bodies at spline_n=12). The small gap this opens between
neighbouring teeth is covered by the disc's own flat top, already at height
0 there, so nothing is left open.

`trough_pullback = (half/nseg) * 0.05` — 5% of the finest existing chord,
so it scales with both `nseg` and `spline_n` automatically. Swept
0.001-0.08 (as a fraction of one chord) at `spline_n` = 4, 6, 8, 12, 24, 36,
48, 72, 96, 180: still non-manifold at 0.001 (barely pulled back — within
CGAL's own numerical noise), clean from 0.005 up at every `n` tried. 0.05
keeps a 10x margin over that measured threshold while moving the trough
vertex by well under 0.02mm at `spline_od/2` — an order of magnitude below
the 0.004-0.026mm contact spread §5 already treats as FDM-invisible.

Only the two boundary samples move; every interior sample (everything §5
and §6 probe: the quarter points, the peak) is untouched, so the tooth
PROFILE away from the exact trough point is bit-for-bit what it was.
Re-measuring §5 and §6 after the fix (numbers now current in both
sections) shows exactly that: the quarter-point row is unchanged to 4
decimal places (0.0258mm both before and after), while the trough and peak
rows — which sample at or adjacent to the pulled-back vertex — shifted by a
few thousandths of a millimetre, still small, still real, still
correctly-signed contact.

### Verification after the fix

```
$ openscad -o stl/gen4-spline-test.stl -D 'part="spline_test"' src/gen4-display-mount.scad
$ python3 tools/check_fit.py report stl/gen4-spline-test.stl
    watertight True
$ openscad -o stl/gen4-yoke.stl -D 'part="yoke"' src/gen4-display-mount.scad
$ python3 tools/check_fit.py report stl/gen4-yoke.stl
    watertight True
```

Both parts: 0 boundary edges, 0 non-manifold edges, 1 connected component,
watertight True. `spline_test` bbox unchanged at 40 × 40 × 4.6mm, `yoke`
unchanged at 103 × 90.1 × 20.5mm, `gauge` unchanged at 101 × 48.6 × 8mm —
the fix is confined to the trough vertex and changes no part's outer
envelope.
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

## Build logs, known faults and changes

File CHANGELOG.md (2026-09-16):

# Changelog

Dates are ISO. This project is pre-1.0; parts land as they are verified.

## Unreleased

### Changed
- **Two-clamp rework (2026-09-15).** The mount now clamps the bar on **both** sides of the centre
  bracket, not one. Owner's verdict on the one-sided design: "we should be attaching on both sides
  of the handlebars. There is a tiny sliver of plastic supporting the entire display" — correct, and
  a two-sided mount had been wrongly argued against at design time.
  **`arm_crank` removed.** Each clamp roots its own spline at its own bare `clamp_x0+clamp_w/2`
  (no offset); the display centres itself between two mirrored pivots instead of being cranked back
  to one. `clamp_x0` changed 1→0 — the clamps now **butt** the bracket's faces rather than standing
  1mm clear of them.
  **`arm_seat()` → `clamp_seat(side)`.** `side=1` (right) is the same translate/rotate this file has
  always used, with `pivot_x` replaced by the new, DERIVED `pivot_x_r` (closed form: solve "what X
  lands the clamp's inboard face exactly on the bracket's own face" for the spline position, instead
  of solving `arm_crank` and checking `bracket_w` against 45mm after the fact — that check is gone,
  replaced by nothing needing to drift). `side=-1` (left) is `mirror([1,0,0])` of that exact result —
  proven, not assumed, safe: the clamp's own solid and the spline's own tooth phase are each provably
  self-symmetric under this mirror (`docs/design-notes.md`), and mirroring about the plane
  perpendicular to the shared hinge axis commutes with the `theta` pitch rotation (so both clamps use
  the same `theta`, not opposite-signed ones) — confirmed against real exported geometry, not the
  algebra alone.
  **Yoke: one female spline → two, mirrored.** New `yoke_leg()` (was the single "lower arm" inside
  `yoke()`) builds the right leg; the left is `mirror([1,0,0]) yoke_leg()`. `yoke_profile()`'s hull
  gained two more anchor circles (one per leg root) so both union onto the (now wider) bearing plate
  generously rather than by a graze. New `leg_w` (18mm, was `yoke_arm_w`=26) — narrower, to clear the
  lone M5's own socket sweep now that neither leg is centred under it (new assertion). New
  `pivot_x_r`/`pivot_x_l` (`=-pivot_x_r`), coaxial with the unchanged `pivot_y`/`pivot_z`.
  **Cowl opening: asymmetric → symmetric again**, `open_x0`/`open_x1` now `±open_half`, sized off
  the same seated-clamp-reach formula (`clamp_seat_x_reach`, was `arm_seat_x_reach`) for one side and
  mirrored — simpler than the single-clamp design's own one-sided opening. M3 boss positions follow.
  **New test parts** `yoke_leg_test` (one leg alone) and `yoke_plate_test` (bearing plate alone) —
  measured by isolation, the same method `spline_test`/`pivot_puck_test` already use, so the
  whole-yoke fill-sanity check in `tools/build.sh` is built from real measurements of the new
  sub-assemblies rather than reused numbers from a differently-shaped design.
  **Screen height above the bar is unchanged (52/146mm)** — the rework only moved things sideways
  (X); every number the height depends on (`arm_len`, `bar_d0`, `pivot_y`) is untouched.
  ⬜ **Left side of the bar is unmeasured** — `bar_d0`/`bar_taper`/`bar_run` are a TEMPORARY
  assumption (mirror the measured right side); flagged at their own definition and in
  `docs/bike-fitment.md`.
  Verified: every part (gauge, spline_test, pivot_puck_test, yoke_leg_test, yoke_plate_test, yoke,
  arm, cap, cowl, brow_test) watertight, 0 boundary edges, 0 non-manifold edges, 1 connected
  component. Whole-yoke volume 66534.6mm³ (0.91× the plate+2×leg overestimate). Cowl clearance CLEAR
  against yoke, both positioned clamps, the display, and the two clamps against each other — each
  positioned clamp's bbox also checked against an independently hand-derived per-axis expectation
  (matched to the mm on the first run). **Pitch acceptance test unchanged and still passing**: three
  7.5° clicks move elevation by exactly 22.500°, roll stays at 0.0000000, hinge-axis drift 0.000000°.
  Every assertion (existing and new) reconfirmed to fire when deliberately broken.

### Fixed (2026-09-16)
- **Swept every part for the tangent problem, and found two more things.**
  | part | on the bed | per mm of height | laid over air | verdict |
  |---|---|---|---|---|
  | `gauge` | 4194 mm² | 524 | **0** | clean |
  | `brow_test` | 3772 mm² | 56 | **0** | clean |
  | `insert_coupon` | 1774 mm² | 118 | 61 mm² | trivial |
  | `cowl` | 11807 mm² | 132 | **4472 mm²** | ⚠️ needs support |
  | `yoke` | 3879 mm² | 97 | 2171 mm² | needs support |
  | `cap` | 312 → **868** mm² | 13 → **48** | 593 → **223** mm² | ⚠️ lay it flat |
  | `arm` | 868 mm² | 48 | 1432 mm² | flat, already changed |

  **The cowl is the worst in the set** despite having the best adhesion. A single **2092 mm² region
  begins 22.4 mm up** — the visor's riser is full width and reaches 12.5 mm past the box's own top
  edge, so it appears in mid-air — with **1183 mm² more at 30.4 mm** as the visor carries on past the
  front rim. Nothing sits under either all the way to the bed, so build-plate-only support reaches
  them. `docs/printing.md` now says the cowl requires support; it previously only listed a
  down-facing area and left it to a slicer preview.
  **The `cap` gets laid flat too**, the same −90° rotation as the arm. Bore-side down it is 312 mm² on
  the bed with 593 mm² over air; flat it is **868 mm² and 223 mm²** — better on *both* counts, unlike
  the arm where flat buys adhesion at the cost of some overhang.
  `gauge` and `brow_test` are the only two parts with **nothing at all laid over air**.
  ⭐ **New printability gate** in `tools/build.sh`: fails on any first-layer island under 60 mm², which
  is what a tangent contact looks like. Proven against commit 89bec7a's yoke, where the two pivot
  discs read **56.6 mm² each**. The "laid over air" figures are reported, not gated — the cowl's
  4472 mm² is legitimate and wants support, not a smaller number.

- **The pivot discs stood on a tangent; they now land on a flat.** Owner: *"it fails where the
  circular part sits off by itself"*, then *"can we make the circular part that is nearest the bed
  connect to it flat? that would fix it"*. Right on both counts.
  ⛔ **The tangency was deliberate, which is the galling part.** `yoke_standoff` was raised to 12
  specifically to bring the Ø40 disc's lowest point to *exactly* z = 0 — its own comment reads
  "touching, not clipping". That solved clipping the bed and created the worst possible first layer: a
  40 mm disc balanced on a mathematical line. Measured, the two discs shared **184 mm²** of first-layer
  contact, fanning to 1745 mm² by 10 mm up.
  **Fixed** with a small foot filling the lens between bed and arc, so each disc lands on a real
  **16 × 10.6 mm flat**. Contact at that end **184 → 339 mm²**; 230.4 mm³ of plastic for both.
  ⚠️ **Additive on purpose.** Lowering `pivot_z` and truncating the disc gives the same flat but removes
  the outer ~1.7 mm of about six teeth and shifts the screen height, invalidating the spline mesh
  proofs. The foot sits under the disc's **rim**; the teeth are on its **face**, so it cannot reach
  them. It is permanent and rotates with the tilt setting, but lives in free space either way — no
  display and no cowl anywhere near y = −70.
- **`tools/check_print.py` was measuring the wrong thing, twice.** It asked whether a connected
  *region* of a layer touched anything below — first "any contact at all", then "at least 20 % held".
  Both reported the yoke clean, because its legs and discs are joined *in-layer* to the bearing plate
  and the plate's area swamps the fraction. What the nozzle experiences is per-position. Counting
  unsupported **voxels** reports **2171 mm² laid over air**, including two 390 mm² patches 9.2 mm up
  where each leg starts a 45 mm cantilever. `docs/printing.md` now states outright that the yoke
  requires support (build plate only) rather than leaving it to a slicer preview.
- **Brim guidance, from the measured first layer.** It is **three separate islands** — plate + ears at
  3512 mm², and the two pivot feet at 183.7 mm² each. **Outer brim only**: it rings all three, where an
  inner brim would only fill the three M5 clearance holes with plastic to pick out.
- **An ASA section in `docs/printing.md`** for the curling: fan off for the first layers then 20 % max,
  enclosure, bed 100–110 °C, Z-hop so the nozzle rides over what has already lifted — and a note that
  halving print speed makes ASA curl slightly *worse*, since each layer has longer to contract before
  the next lands.

- **The arm's print orientation changed, after two prints in a row turned to spaghetti.** Standing
  "bore-side down" it is a **65 mm tower on 262 mm² of bed contact — 4 mm² per mm of height**, where
  every other part here sits between 11 and 515. Laid flat (bore vertical) it is **18 mm tall on
  868 mm²**: 2.8× the grip, a third of the height. Cost: two 17 mm² islands start 2 mm up and want
  support. It also settles the layer-direction question `docs/printing.md` had left open — laid flat,
  the rib's bending load lies *within* the layer plane rather than across it.
  ⭐ **New `tools/check_print.py`**: slices the part and asks, for every island of material in every
  layer, whether anything is in the layer below. That is the question the total down-facing area never
  answered — a big down-facing area can be entirely benign (a bore ceiling bridges) and a tiny one
  fatal (a feature beginning in mid-air). Also reports bed contact against height, which is what
  actually put the arm on the floor. All seven parts now report **no layer starting in mid-air**.

- **The yoke's cowl-fixing ears would not print.** Owner, mid-print: *"the ears are shrinking and
  lifting off of the plate."* Not a settings problem — the geometry was asking for the impossible.
  `cowl_fix_ear_z0` was 2.5, holding each ear clear of the display "for safety". That left its
  underside **0.8–2.4 mm above the bed across 21 mm of span, sloping 5° from horizontal** — a flat
  shelf printed into thin air, at the outermost corners of a 144 mm ASA part, which is exactly where
  shrinkage pulls hardest. Measured on the export: the part touched the bed only out to x = ±50.7
  while reaching ±71.9.
  **Fixed** by dropping the ear's underside to **z = 0, coplanar with the bearing face**, so it lies
  flat on the bed. ⚠️ The original reason for holding it clear does not apply to a *coplanar* surface:
  that is not a second contact plane, it is more of the same one, so it cannot rock the plate — only
  something standing **proud** of the bearing face could. Outside the flat band the shell chamfers
  away, so the worst case is that the ear bears on nothing, which costs nothing.
  ⚠️ Two passes were needed. The first moved only the boss to z = 0 and left the root and mid stations
  at 0.5, sloping the underside 1.2° over 23 mm — still a horizontal overhang, and 8 of 10 sampled
  columns still began above the bed. **Every station has to share one underside plane**, or it is not
  fixed.
  Result: footprint now reaches the full **±71.9 mm**, bed contact **3133 → 3745 mm²**, off-bed
  overhang **3560 → 2946 mm²** (what remains is the spline pucks, which were always there), and
  **0 of 10** ear columns begin in mid-air.
  ⚠️ **The overhang number was already in front of me and I did not act on it.** The 2026-09-16 audit
  recorded the yoke's down-facing area rising 2644 → 3560 mm² when the ears were added, and filed it
  as a stale figure to update rather than asking *where* the new 900 mm² was. A measurement that moves
  35 % is a question, not a line to correct.
- **`docs/printing.md` gained an ASA section** for the two wide parts — enclosure, bed temperature,
  fan under 20 %, brim — and the overhang table now reads 2946 mm² for the yoke.

### Audit (2026-09-16)

A full pass over every part, joint, assertion and document. What it found:

- **A tautological assertion.** `VISOR WIDER THAN THE COWL` read
  `brow_edge_x + brow_d_s/2 <= disp_w/2 + reveal`, and `brow_edge_x` is *derived* as
  `disp_w/2 + reveal - brow_d_s/2` — the two sides are identically equal, so no parameter could ever
  break it. Written when `brow_edge_x` was independent, never revisited when it became derived. ⛔ **An
  assertion that cannot fail is not a test.** Replaced with two that can: the visor must stay at least
  as wide as the cowl's corner radius allows, and its edge section must be thinner than its centreline.
  Found by trying to break all 59 assertions; this was the only one that could not be broken.
- **A hardcoded number that would have gone stale.** The cowl-ear/socket clearance assert carried the
  literal `45.25` — `p(holes[1])[0] + m5_socket_d/2` worked out by hand. Now derived.
- **The whole-yoke fill expectation had stopped over-estimating.** It was `plate + 2×leg`, written
  before the yoke grew a gusset, two pivot nut pads and two cowl ears. The ratio had climbed to
  **0.995 against a 1.05 ceiling** — passing because the formula did not know about a third of the
  part, and one more gram of material would have failed the build for no reason. Now includes the ears
  (measured) and the nut pads (analytic, deliberately double-counting what is buried in each leg):
  ratio **0.850**.
- **The insert count was wrong in two documents.** README said 8, `docs/assembly.md` said 4. Counted
  on the exported parts: **6** — two per clamp arm (and there are two arms), two in the yoke.
- **The pivot hardware row said `1 × M6`** when there is one per side, and "length set by your stack"
  when the length is now derived and asserted. Now `2 × M6 × 35` + nyloc + plain washer.
- **Stale printability figures.** The yoke's down-facing area is **3560 mm²**, not the 2644 recorded
  before it grew ears (+35 %); cowl 4902 → 5148; arm 1276 → 1287. Added the `insert_coupon` row and a
  bed-size note: the yoke's footprint is now **143.8 × 107.1 mm**, the largest single part.
- **`docs/design-notes.md`'s arm throat** 234 → 236.9 mm², after the pivot head seat was counterbored.

Verified clean, with measurements rather than assertions:

- All seven printable parts watertight, one connected component, no non-manifold edges.
- **Neck scan** (new): every part survives 0.5 mm of erosion in one piece.
- **All three display bolts**: clear bore, head seat flat to 0.00 mm across its annulus, socket sweep
  unobstructed.
- **All four clamp bolts**: head seats at z = −5.5 in the cap, crosses the 2 mm pinch gap, engages
  5.0 mm of insert — matching the model's own derived `ear_bolt_engage`.
- **Both pivots**: bore clear through, both bearing faces flat to 0.00 mm, 26.00 mm of measured grip
  against 26.1 derived.
- **Both cowl screws**, every clearance pair, the pitch test and the shade test: unchanged and green.
- A **clean `git archive` export** builds end to end under a venv holding exactly the packages CI
  installs.

### Added
- **`tools/check_necks.py`** — voxelise a part, erode it, and report what falls off. ⚠️ Validated
  against this project's own four defects rather than assumed to work: it catches the arm's 0.2 mm
  knife edge (at 0.5 mm) and the yoke's 36 mm² shear web (at 1.5 mm), and **does not** catch the
  cowl-ear bond or the deleted boss. Those are different failure modes and have their own gates; the
  docstring says so.
- **`--sweep all` on `tools/check_throat.py`** — plane normals over a whole hemisphere, including
  normals along X that the Y-Z sweep never tried. ⛔ It still does **not** catch a corner-graze bond,
  and the tool now says why: the plane that comes closest to separating a feature also slices a large
  area of parent carrying none of that feature's load.

### Added
- **Exploded view** (`part="exploded"`, `renders/gen4-exploded.png`) — every part pulled apart along
  the axis it actually assembles on, with all 17 fasteners and 8 inserts shown in place.
- **`insert_coupon`** — heat-set insert fit gauge: eight pockets, two fits each for M3/M4/M5/M6.
- **`tools/check_fixing.py`** — walks a screw's axis through two exported meshes and reports what is
  actually there.
- **`tools/check_throat.py`** — smallest verified load-bearing section, sweeping the cutting plane's
  angle instead of picking one.
- **Four new renders** (`tools/render-gen4.sh`): `gen4-assembly-rider.png` (the view from the
  saddle), `gen4-assembly-threequarter.png`, and `gen4-visor-plan.png` / `gen4-visor-profile.png` —
  the two views the visor's shape is actually judged in (its plan silhouette, and how far it reaches
  past the glass).

### Fixed
- **The cowl's side ears were barely attached to the yoke (found by eye, 2026-09-15).** Owner, from
  the top view: *"the new ears are barely connected."* Measured: each ear shared **2.3 mm³** with the
  bearing plate, out of its own 6670 mm³. It was effectively a floating wing touching at a corner.
  **Cause: the plate is a truss, not a rectangle**, and its outer edge runs diagonally — measured on
  `yoke-plate-test.stl` it reaches x=51.5 at y=+6, x=46.0 at y=−4 and x=39.0 at y=−12. The ear was
  placed at y=−4 starting at x=51, which put its root **5 mm outboard of the plate altogether**.
  **Fixed** by moving the joint to **y=+6**, the plate's own widest line, and rebuilding the ear as
  three hulled stations instead of a constant-section bar: a root at x=40 buried inside the plate, a
  mid station at x=49 still flush within `yoke_t`, then the cantilever out to the boss at x=71.8. The
  root→mid leg stays at or below `yoke_t` deliberately — above it lies the Ø9.5 socket sweep of the
  upper M5 at (40.5, 6.09), and a rib crossing that makes the display bolt impossible to drive
  (asserted). Bond **2.3 → 2607.8 mm³** (30.5 % of the ear now inside the plate); minimum section
  along the run 84.1 → 110.8 mm².
  ⛔ **No section scan can catch this, at any angle.** `check_throat.py` was extended with `--sweep
  all` (Fibonacci-hemisphere plane normals, including normals along X, which the Y-Z sweep never
  tried) and it still reported a healthy **112 mm²** on the broken geometry. That is not a gap in the
  sweep: the plane that comes closest to separating an ear also slices a large area of *plate* that
  carries none of the ear's load, and the cut reports that area. **A section measures a neck; it
  cannot measure whether two solids are really one.**
  ⭐ **New cowl-ear bond gate** in `tools/build.sh`: exports the ear alone (new `yoke_ear_test` part)
  and the plate alone, intersects them, and requires ≥1500 mm³ of shared volume. The broken geometry
  scores 2.3.
  ⚠️ Moving the joint also invalidated the cowl-fixing gate's hardcoded probe axis, which still read
  y=−4 — and the gate said so immediately ("34.60 mm gap … the screw spans air"), which is the right
  failure to get from a stale probe rather than a silent pass.
- **The pivot bolt could not be fitted (found by eye, 2026-09-15).** Owner: *"When I looked at the
  yoke, there was no hole to feed a bolt through."* Correct, and three separate things were wrong:
  **(1) The bore did not go through.** `yoke_leg_bore()` started at the puck's own root face and ran
  OUTWARD, on the reasoning that the puck's root is the near face "as the bolt is offered up from
  that side" — but the bolt is offered from the ARM, i.e. outboard, and has to exit the far side for
  its nyloc. The leg's Stage C material continues inboard of the puck and left a solid plug measured
  at x = 13.75–17.75: **4.25 mm of ASA between the bolt's tip and daylight.**
  **(2) The nut had nothing square to sit on.** Once bored through, the face the nyloc lands on was
  the leg's own taper flank, wandering **2.6 mm across the nut's Ø10 footprint** (11.60–15.95 across
  Ø20). A nut pulled onto a slope cocks, bears on one edge and relaxes as the ASA creeps — on the
  joint that holds the screen's angle.
  **(3) The head could not be inserted.** The rising rib joins the arm's tip puck 1.1 mm PROUD of its
  face, inside a Ø10 head's footprint and across its insertion path. Sinking a counterbored seat did
  not fix that on its own — the first attempt left the seat flat at x = 34.90 with the rib still at
  38.55, in front of it; the bore now runs `pivot_head_clear` outward past the face as well as into
  it. A second iteration was needed there too: the lead-in cone ran from the seat's full Ø11.5 down
  to the bore, which is not a lead-in but a 0.6 mm taper across the whole bearing face, and the gate
  measured 0.35 mm of slope where the nut read 0.00.
  ⛔ **The only assertion on this bore checked that it was not too WIDE** (`pivot_bolt_clear_d <
  spline_id`). Nothing asked whether it went through, landed on anything square, or admitted a head.
  **Fixed:** the bore starts at the leg's own inboard face; a `yoke_nut_pad()` boss gives the nut a
  flat out at the leg's nominal plane (chosen over a measured number so it stays proud if the taper
  is ever re-shaped); the arm gets a counterbored head seat that also clears the rib. Both faces now
  measure **flat to 0.00 mm** across their own bearing annulus.
  ⭐ The bolt's length is now **derived from the stack rather than carried by hand** — `pivot_grip =
  leg_w/2 + yoke_tip_h + spline_seat + arm_tip_h − pivot_head_sink` = 26.1 mm → **M6 × 35** with a
  1.6 mm washer, 7.3 mm into the nut, asserted against both a too-short and an absurdly-long bound.
  ⭐ **New pivot gate** in `tools/build.sh`: walks the real axis through the real exported parts in
  the assembled frame and checks all three failures at once — clear through, grip matching the
  model's own derived figure within 0.6 mm, and both bearing faces flat to 0.3 mm over the annulus
  the fastener actually touches (not inside it, where the bore's own chamfer lives).
  ⚠️ One more trap recorded in passing: `yoke_pivot_bore_x0` was first written as a top-level
  assignment reading `pivot_x_r`, which is defined much further down the file. It silently evaluated
  to `undef`, put the bore at x = 0, drilled through the middle of the bearing plate, and CGAL
  reported `Volumes: 4` — the part in three pieces. Module *bodies* resolve at instantiation;
  top-level assignments do not.
- **The yoke's legs hung off the bearing plate by a 36 mm² shear web (found by eye, 2026-09-15).**
  Owner, looking at the side view: *"there is only a thin bit of plastic connecting where the back of
  the part mounts to the display to the rest of the yoke, this should be thicker."* Correct.
  ⛔ **And the load-path section scan added the same day passed it at 194.6 mm².** That scan cuts
  perpendicular to Y; Y is the one direction the web looked thick in. Stage A has to climb 13 mm of Z
  across the 2.32 mm of Y the flat-band guard allows (a 5.6:1 slope), so the join was an 18 mm wide,
  ~2 mm thick sheared web. Cut at 72-78°, the way the load peels the leg off the plate, the verified
  plate→pivot throat is **36.4 mm²**.
  **Fixed** with a gusset, not a wider Stage A — the 2.32 mm is forced by a real clearance constraint
  (low-Z material must stay inside the display's flat band). The load now also runs through the one
  region with no clearance constraint at all, directly above the bearing plate: a wedge buried
  `yoke_gusset_bite` (3 mm) into the plate's top face, running north to `yoke_gusset_clear` (3 mm)
  short of the boot's relief pocket, ramping up to meet the riser. The plate is solid 18-of-18 mm
  under the leg's whole X band there — measured on `yoke-plate-test.stl`, not assumed — so the
  gusset's underside is fully carried: no overhang added, the yoke's down-facing area is unchanged at
  2644 mm², and it still prints with no support. Throat **36.4 → 182.2 mm² (5×)** for 4.3 cm³ of
  plastic (yoke volume 66534.6 → 70787.3 mm³). The minimum on the path is now the leg's own uniform
  run rather than a junction.
  ⭐ **New permanent throat search** (`tools/check_throat.py`, gated in `tools/build.sh`): sweeps the
  cutting plane's angle instead of picking one, and reports the smallest section that *verifiably
  separates* the load's origin from its destination — the part is cut and the piece holding the
  destination must not hold the origin. Without that separation test the search only finds the part's
  own edges, where area tends to zero. Gates the yoke at 150 mm² and the arm at 200 mm²; ~20 s per
  part. Proven to fire against the pre-gusset yoke (36.7 mm²). The arm was measured on the same swept
  basis rather than assumed healthy — it comes out at **234 mm²** against its 261.6 mm² axis-aligned
  minimum, so it has no hidden weak plane. That is a result, not a foregone conclusion.
- **`brow_test`'s stated print orientation was the worst of the six.** `docs/printing.md` said
  "flat", which measures **8874 mm²** of steeply down-facing area; standing it on its riser with the
  visor pointing up — the same way up as the cowl, since the visor narrows all the way to its tip —
  measures **0 mm²**. Corrected. The same section's blanket claim that "every part prints unsupported
  in the orientation above" had never been measured either; it is now replaced with the per-part
  numbers, the caveat that a horizontal bore's ceiling is not a support problem, and an explicit ⬜ on
  the `yoke`/`arm` spline orientations that have been open since the tilt-axis fix.
- **`tools/render-gen4.sh` could not run in a clean clone.** It still carried the two hazards
  `tools/build.sh` was fixed for on 2026-09-14: a hardcoded `/root/.venvs/revv1/bin/python`, and a
  `../tools/check_fit.py` path pointing **outside the repository**. Now resolves the interpreter the
  same way `build.sh` does (`$REVV1_PY` → local venv → `python3`) and uses the vendored
  `tools/check_fit.py`.
- **The sun visor shaded nothing, and then shaded too little (2026-09-15).** Owner: *"The 'brow'
  doesn't even reach across the top, the point of it was to block sunlight, that blocks nothing."*
  Two separate defects, found in that order.
  **(1) It pointed the wrong way.** `brow` was measured off the cowl's own rear face, not off the
  glass, so a "19mm brow" put its tip at z=-19 with the glass at z=-26 — **7mm behind the surface it
  was supposed to shade**, projecting backwards. Measured shade at every sun angle: **0.0%**. The
  acceptance criterion had been "the brow projects `brow` mm", which the part satisfied exactly; it
  measured the mechanism, not the job — the same failure mode as the tilt joint that rolled instead
  of pitching. `brow` is now the TRUE projection past the glass plane and is **33mm**.
  **(2) Reaching further did almost nothing.** With the tip out past the glass the visor still
  shaded only **14.8%** at 45°. Stretching projection to 45mm gave 17.2% and to 60mm gave 20.4% —
  and the shadow's depth down the screen did not move at all, 14.1mm in every case. The straight
  taper had narrowed to a 2mm spike by mid-projection, so the screen's outer columns were in full
  sun however far the spike reached. **Width, not projection, is the lever** — measured, not argued.
  **Fixed** by making the plan curve a **superellipse** (`brow_plan_n`=3, `brow_stations`=14 lofted
  sin-spaced stations clustered at the nose): full width at the glass plane, holding most of it for
  most of the run, then turning back to a blunt rounded nose. Same 33mm projection, same rounded
  silhouette the owner asked for. `brow_edge_x` also corrected from `disp_w/2 - disp_corner_r` (=71)
  to `disp_w/2 + reveal - brow_d_s/2` (=79): the old value applied the box's own R9 corner logic to
  a feature that sits entirely above the box, carried by the full-width **riser**, leaving the visor
  9.5mm per side narrower than its own support and a visible width crease in plan view.
  Result: **27.7% shaded at 45°** (was 0.0%, then 14.8%), 49.3% at 60°, 94.0% at 75°; shadow depth
  28.2mm (was 14.1mm). The visor's underside stays **flat**, deliberately — it extends toward the
  rider, so anything that shades the sun at a given angle also blocks the rider's eye at it; shade
  above ~45° is what the tilt joint is for.
  ⭐ **New permanent sun-visor shade test** (`tools/check_shade.py`, gated in `tools/build.sh`):
  ray-casts the glass from the sun at 45/60/75° **off the screen's own normal** and fails the build
  below 20% at 45°. Proven to fire — the shipped-and-committed old brow scores 0.0% and fails by 20
  points, and the straight-taper shape scores 14.8% and fails too.
  The cowl's own fill gate was re-derived for the new solid visor (its expectation still modelled a
  19mm hollow full-width prism) and its floor tightened 0.60 → 0.66: at the shipped 0.733, deleting
  the visor reads 0.51 and losing half of it 0.62 — both now fail, where the old floor passed the
  half-lost case.
- **The clamp-to-spline rib had collapsed to a 0.2mm knife edge (found by eye, 2026-09-15).** Owner:
  *"Ensure that there is enough material holding the clamp to the handlebars to the toothed piece.
  It looks very thin."* They were right — a station-by-station section scan of `arm()` (intersect
  with a 1mm slab, volume ÷ thickness) found the rising rib's "vertical riser" stage down to
  **4 mm²**, not the ~160mm² its own comment assumed: two `taper_wp()` waypoints at the *same* Y
  cannot gain any real Y-thickness from a `hull()` between them (a convex hull is bounded by the
  union of its inputs' own Y-range, the same rule this file leans on everywhere else — here it was
  working against the design). Every existing check — watertight, 0 boundary, 0 non-manifold, 1
  component, whole-part volume, clearance, a normal render — stayed green throughout; none of them
  measure a cross-section. **Fixed** by widening the riser to a real Y-span (new
  `clamp_riser_y0`/`clamp_riser_y1`, 14mm, inboard of the clamp tube's own edges) instead of a
  single Y — that stage now measures a flat **284.00mm²** across its whole z=24..26 floor,
  comparable to its neighbours (307-592mm² either side). The **scanned load path's** own minimum is
  **261.61mm² at z=0**, the clamp end — a different feature, and above the 200mm² floor. Also corrected in passing: the
  yoke leg's own documented minimum was itself a never-measured hand estimate (144mm² claimed,
  ~119mm² actual — `docs/design-notes.md`), and `arm_w`'s own comment had the wrong axis (claimed Y,
  is actually X) since the ⚠ DM-6 axis rework.
  ⭐ **New permanent load-path section scan** in `tools/build.sh`: the same slab-intersection method
  (no shapely needed), run at 1mm stations along `arm.stl`'s clamp→spline path (floor 200mm²) and
  `yoke-leg-test.stl`'s own path (floor 100mm², reflecting its different, already-reasoned minimum)
  — fails the build if either drops below its floor. Proven to fire: reproduces the 4mm² defect
  against the pre-fix geometry, and independently catches a synthetic `leg_w=6` yoke-leg thinning
  (~46-65mm²) that clears every pre-existing assertion.
- **The tilt joint now actually tilts (⚠ DM-6 re-derived).** The face spline's axis was the
  display's own normal, so rotating the joint rolled the screen in its own plane instead of
  pitching it — found 2026-09-14 during assembly rendering. Re-derived DM-6 for an axis parallel
  to the bar: the yoke's female spline boss now grows sideways (model +X) off a re-worked lower
  arm (new `yoke_approach_y`/`yoke_pivot_puck()` stages; `pivot_x`/`pivot_y`/`pivot_z` replace the
  old single `pivot_c` point); the arm's own tip stack and male spline are rotated onto the same
  axis; `arm_seat()` is rebuilt from scratch for the new seating geometry (base rotation
  `rotate([0,-90,-90])`, a theta-dependent translate that pivots about the physical hinge line
  rather than the origin). New top-level `arm_seat_theta` parameter (0 is the reference pose; any
  multiple of 7.5° re-meshes exactly and picks a different pitch).
  **Cowl opening widened and made asymmetric** (`open_x0`/`open_x1` replace the old symmetric
  `open_w`): with the axis fix the arm's clamp reaches out along shared X (the bar's own length)
  by a real, theta-independent amount instead of into depth, and the old ±25mm opening was too
  narrow on the clamp's own side (found via `check_fit.py`: 1361-2729mm³ of real interference,
  cowl/display vs the positioned arm and cap). M3 boss positions (`m3_x_left`/`m3_x_right`) follow
  the new asymmetric opening.
  **Screen height above the bar moves from 35mm to 52mm** (top edge 129→146mm) — the display's own
  clearance from the pivot and the pivot's own clearance from the clamp now stack on the same axis
  instead of two independent ones; see `docs/bike-fitment.md` and `docs/design-notes.md`'s DM-6.
  ⭐ **New permanent pitch acceptance test** in `tools/build.sh`: two pairs of marker rods
  (`pitch_probe_fixed`/`pitch_probe_arm`, new parts) exported at `arm_seat_theta` = 0/7.5/15/22.5°
  prove, on real geometry, that the display's elevation changes by exactly the click step (a
  3-step rotation moves pitch by 22.5°) while roll and the hinge axis itself stay fixed — this is
  the check that was missing before and the reason the defect survived every other one (mesh
  health, clearance, and the spline's own meshing proof all say nothing about which axis the joint
  turns on).
  ⚠ **Two bugs caught and fixed during this same rework, before either shipped, by the rod-probe
  method `docs/spline-verification.md` §4 mandates for this geometry** (neither a render nor
  `check_fit.py` could have caught them — the codebase's own established policy is that a
  whole-spline-ring boolean is never trustworthy, so yoke-vs-arm is deliberately never intersected):
  (1) `arm_seat()`'s base rotation had the wrong sign on which way "up the rib" maps to shared Y,
  putting the clamp cap back up inside the display/yoke (caught by `check_fit.py`, 400-2700mm³ of
  real interference on 4 pairs) — fixed to `rotate([0,-90,-90])` with a re-solved translate.
  (2) the male spline's own translate omitted `yoke_tip_h` (the female boss's own standoff from
  its root), landing the male's solid base disc 1.7mm deep into the female's at every angle sampled
  — invisible to every other check because nothing ever booleans yoke against arm. Both fixed and
  re-verified by rod probe (male/female overlap now ~0.09mm, closed by the M6 pivot bolt's own
  clamping — consistent with the same eps convention already used, unflagged, elsewhere in this
  construction).
  `yoke_standoff` raised 8→12mm: the pivot puck is now a full-diameter disc *centred* on
  `pivot_z`, not a flat cap sitting on top of it, so its own lowest point is `pivot_z-spline_od/2`
  — at the old value that was −4mm, below the bearing face's own z=0 in the "bearing face on the
  bed" print orientation (`docs/printing.md`). New assert (`PIVOT BELOW THE BED`) guards it.
  `docs/printing.md`'s arm/yoke orientation rows flag the spline's own print orientation as an open
  question (its disc is no longer a flat face at either Z extreme, so "spline face down" no longer
  has a direct equivalent) rather than repeat the stale pre-rework guidance; `plate()`'s bboxes
  re-measured and the arm's Z-flip removed (its bore-side is already at z=0, unchanged) to match.
  New `pivot_puck_test` part + build.sh check (puck volume vs. a closed-form frustum+disc formula,
  0.999 ratio) and a whole-yoke volume sanity check, guarding the new pivot geometry the same way
  the historical hollow-tooth defect is guarded.
  All clearance pairs re-verified CLEAR on the corrected geometry (`tools/build.sh` and
  `tools/render-gen4.sh`); `tools/render-gen4.sh`'s assembly camera angles re-derived (shared Y is
  now the display's vertical axis and shared Z is depth — swapped from before the fix; the old
  iso/side/front rotations looked along the wrong axis and showed the display edge-on).

### Added
- **Assembly view, print plate, and `tools/render-gen4.sh`.** `assembly()` positions every part as
  it actually assembles — display, yoke, cowl, arm, cap, handlebar and centre bracket (the last two
  as stand-ins; not printed), each a distinct `color()`. The arm/cap/bar/bracket are seated with
  `arm_seat()`, the same transform `tools/build.sh`'s own cowl-clearance check already derived and
  proved, reused verbatim rather than re-derived (confirmed bit-identical against that check's own
  positioned export before relying on it). `plate()` lays the 4 printable parts flat in the print
  orientation `docs/printing.md` specifies (yoke and cap need only a mirror or no transform at all —
  their "down" face is already at their own Z=0; arm and cowl need a mirror plus a translate by
  their own Z maximum — verified against each part's real exported bbox, not guessed). One new
  `assert()`: the handlebar bracket stand-in's width, derived from `arm_crank`/`clamp_x0`/`clamp_w`,
  must still equal `docs/bike-fitment.md`'s stated 45 mm.
  Verified: `display`/`yoke`/`cowl` vs the POSITIONED `arm`/`cap` all CLEAR with `tools/check_fit.py`
  (5 new pairs, plus 3 already covered by `build.sh`'s own check, re-confirmed) — every pair except
  yoke-vs-arm, whose only real contact is the spline teeth and is proven instead in
  `docs/spline-verification.md` (a whole-ring boolean there is not trustworthy either engine).
  `tools/render-gen4.sh` exports every STL and every PNG (7 single parts, the plate, and the
  assembly's iso/side/front) in one command; every PNG call greps openscad's own output for `ERROR`
  and fails the run on a match, since PNG export exits 0 on a fired `assert()` or an unrecognised
  `part` alike — demonstrated against a deliberately bogus part name.
- **Arm + clamp cap** — the handlebar-side mount. Bore is a tapered cone (`bore_at()`) matching the
  bar's own measured 1:10 taper (`docs/bike-fitment.md`), not a cylinder; split clamp with a
  `pinch_gap` at two M5 ear bosses (heads counterbored into the cap); the arm carries `arm_crank` so
  the screen centres on the bike and the male spline up to the pivot. Six new `assert()` guards.
  Verified: bore diameter measured at both ends against `bore_at()` (±0.01mm, facet tolerance); a
  cylindrical bore at the mean diameter shown to interfere with the real tapered bar by 219.5mm³
  (`tools/check_fit.py`); male spline proven CLEAR against the yoke's female when correctly seated,
  and a deliberate half-tooth-pitch misalignment shown to collide (1.5mm³, 96 contacts); arm and cap
  proven mutually CLEAR at the bore and both ears. Both parts watertight, 0 non-manifold edges, 1
  connected component.
- Repository structure, documentation and CC BY-SA 4.0 licence.
- **Fit gauge** — the first part to print. 101 × 48.6 × 8 mm, verified single body.
- Parametric model core: the display's canonical geometry, the `p()` doc-coords→model mapper,
  shared `hole_pattern()` / `boot_slot()` modules, and eight `assert()` design guards.
- `tools/check_stl.py` — bounding-box verification for exports.
- `docs/display-geometry.md` — the full measured geometry of the `CJ-V5-04`'s rear face.

### Confirmed on hardware (2026-09-13)
- **The hole pattern is confirmed** — a printed gauge bolted to a display with all three M5 × 12.
- **M5 × 12 into 8 mm parts is the right pairing** — 4 mm engaged, no bottoming.
- **The flat bearing band is 23.0 … 71.6**, ~6 mm narrower than the manual's side elevation implies.
  Yoke footprint narrows accordingly.

### Notes
- Bolts are **M5 × 12 into 8 mm parts** — 4 mm engaged in a 5 mm thread. The gauge is the same
  thickness as the yoke so it tests the real joint rather than a proxy.

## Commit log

2026-09-13 Initial commit: parametric bar mount for the Chaojie CJ-V5-04
    A 3D-printable handlebar mount and rear cowl for the Chaojie Gen 4 5"
    touchscreen, which ships with no bracket of any kind.
    What is here:
    - The display's full rear-face geometry, derived from the factory manual's
    dimensioned drawing and cross-checked four ways, with thread size, depth
    and orientation confirmed on a physical unit. This is the reusable part
    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
    [gen4-display-mount.scad, gen4-gauge.stl]
2026-09-13 Correct the flat bearing band from hardware: 23.0..71.6, not 20.0..74.6
    The fit gauge was printed and fitted to a display. Three results.
    Confirmed:
    - The hole pattern is real. All three M5 x 12 bolts pulled the gauge tight,
    so (39.50, 40.9), (120.50, 40.9) and (80.00, 63.28) are no longer
    drawing-derived figures.
    - M5 x 12 into 8 mm parts is the right pairing. 4 mm engaged in a 5 mm
    thread, no bottoming.
    - The gauge sat flat, so the bearing surface is genuinely flat.
    Corrected:
    - The flat band is ~6 mm narrower than the manual's side elevation implies.
    A gauge cut to 20.0..74.6 overhung by ~3 mm at each end, hanging over the
    chamfer rather than touching.
    The reason is worth rec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
    [gen4-display-mount.scad, gen4-gauge.stl]
2026-09-13 docs: state the specification, not how it was arrived at
    Strip process narrative from the documentation. A reader needs the
    dimension and the constraint it protects, not the history of how the
    number was found.
    Kept where it changes what a reader does: that frame- and display-side
    figures are measured on one unit and should be confirmed; that a figure
    derived from the manual's side elevation runs optimistic; the known rough
    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
2026-09-14 Add the yoke and the tilt spline; document fitting it to the bar
    Two parts land: the face spline (the toothed tilt joint) and the yoke,
    the only part that touches the display.
    Both needed geometry proved by measurement rather than by looking at it.
    The spline's first tooth profile rendered correctly and did not mesh - a
    hull() between trough points follows a straight chord rather than a
    constant-radius arc, bowing the flank 0.43 mm at mid-radius and putting
    ~330 mm3 of interference into a joint that appeared perfect. It is now
    built as a chain of short hulls with every height taken from the exact
    triangular-wave formula. The yoke hit the same class of problem one level
    down: a single hull f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
    [gen4-display-mount.scad, gen4-gauge.stl, gen4-spline-test.stl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]
2026-09-14 Yoke: add the guard a comment falsely promised, drop the unreachable one
    Two defects found in review, both in the assertions rather than the
    geometry.
    A comment claimed yoke_standoff was guarded by an assertion named
    yoke_riser_z1. No such variable or assertion existed anywhere in the
    file. Sweeping the value showed 1, 3 and 5 all render silently and
    produce a two-body split - exactly the failure the arm's waypoint
    construction exists to prevent, undetected. That is worse than a missing
    guard, because the comment tells the next reader the case is covered. It
    is now a real named guard, TIP TOO LOW, verified firing at 1/3/5 and
    passing at 6/7/8.
    ARM ROOT OFF THE BAND could never fire - RISER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
    [gen4-gauge.stl, gen4-spline-test.stl, gen4-yoke.stl]
2026-09-14 Close the offset() collapse at the primitive instead of per call site
    The same failure has now been fixed three times: a rectangle run through
    offset(r=X) offset(delta=-X) returns EMPTY for any dimension at or under
    2X, the feature silently vanishes, and the part becomes two bodies with a
    plausible bounding box and no error. First it was the arm root's length,
    then its width, and each fix guarded only the instance that had bitten.
    The third instance is the one that shows why per-site guards were the
    wrong shape of fix. taper_wp() takes yoke_t as a waypoint height, and
    yoke_t is pinned only indirectly - by the M5 engagement assertions
    requiring m5_len - yoke_t to fall in 3..4mm. m5_len = 8 i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
    [gen4-display-mount.scad, gen4-gauge.stl, gen4-spline-test.stl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]
2026-09-14 Arm and clamp cap; make the spline mesh watertight
    Two pieces land: the handlebar clamp arm carrying the male spline, and
    its cap.
    The bore is a CONE, not a cylinder, because the bar is tapered 1:10
    through the clamp zone. That is not a stylistic choice and the evidence
    is in the repo: a mean-diameter cylindrical bore, intersected against the
    real tapered bar, interferes by 219.5 mm3 across the inboard 11 mm of an
    18 mm clamp. Across that width the diameter changes 1.8 mm, about nine
    times print tolerance, so it cannot be squeezed out.
    Separately, face_spline() was producing a non-manifold mesh - zero holes
    but 80 edges shared by more than two faces at 48 teeth. Every tooth is
    the same cod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
    [gen4-arm.stl, gen4-cap.stl, gen4-display-mount.scad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]
2026-09-14 The spline teeth were hollow; fill them, and gate on volume
    Each tooth segment was a hull() of four points - two radii at one angle,
    two at the next, all at profile height. A convex hull's z-extent is
    bounded by its own vertices, so every segment occupied only the thin band
    between its two endpoint heights. Only the segments touching a trough
    reached the base disc. Everything else was a shell floating above air.
    Measured: at the quarter point, solid material existed only in a 0.077 mm
    band with 95% of the local tooth height empty beneath it. At the peak, a
    1.0-1.4 mm void under a 0.19-0.6 mm roof. The teeth contributed 44 mm3
    where a solid ridge set needs about 915.
    The fix hulls eight poi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
    [gen4-arm.stl, gen4-cap.stl, gen4-display-mount.scad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]
2026-09-14 Cowl and brow test piece
    The visible part: a 2.4 mm shell over the whole rear face with an
    integrated sun brow, a single bottom opening carrying both the yoke's arm
    and the loom, and retention by a hooked lip plus two M3 entered from
    inside that opening so nothing is visible from the front.
    Two real defects were found by measuring the exported mesh rather than
    looking at it.
    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
    [gen4-arm.stl, gen4-brow-test.stl, gen4-cap.stl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]
2026-09-14 Assembly, print plate and renders - and a design defect they exposed
    Task 6 adds assembly(), plate(), and tools/render-gen4.sh producing 11
    PNGs including the assembly views the README had been promising.
    Two transform bugs were found and fixed on the way: arm_seat() placed the
    handlebar running vertically up the bike, 52-85 mm behind the display,
    with arm_crank never applied; and the assembly cameras had the right axis
    but the wrong sign, so "up" rendered at the bottom of the frame. Both were
    caught by looking at renders, not by any numeric check - and the eight
    positioned clearance pairs had all reported CLEAR throughout, because a
    part in the wrong place is genuinely clear of everything.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
    [gen4-arm.stl, gen4-brow-test.stl, gen4-cap.stl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]
2026-09-15 Re-orient the tilt joint so it actually tilts
    The spline axis ran along the display's own normal; a tilt hinge needs it
    parallel to the bar. The yoke's spline boss now grows sideways along X,
    the arm's male spline matches, and arm_seat() was rebuilt around a
    theta-dependent rotation about the physical hinge line.
    DM-6 was re-derived rather than patched. Its requirement - the lone M5's
    head must stay fittable - was always real, but its solution assumed a disc
    lying in the display's plane. With the axis along X the disc lies in YZ,
    so clearance now comes from Y alone: the pivot sits 70 mm below the
    display's centre and the disc's near edge clears the housing by 3 mm,
    which clears the bolt hea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
    [gen4-arm.stl, gen4-brow-test.stl, gen4-cap.stl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]
2026-09-15 Propagate the tilt-axis fix through the documents
    Task 7: push what the build proved back into everything that stated it.
    The design record's DM-6 and its pivot section are rewritten rather than
    annotated. The requirement they encoded - the lone M5 must stay fittable -
    was always real; the solution assumed a disc lying in the display's plane
    and is void now the axis runs across the bike. Clearance comes from Y
    alone, the pivot is model-space rather than a doc-coordinate point, and
    the screen height is recorded as 52 mm with the reason it moved.
    The section also records the check that was missing, because that is the
    transferable part: every test this design had verified that the joint
    work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
    [gen4-arm.stl, gen4-cap.stl, gen4-cowl.stl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]
2026-09-15 Two-clamp mount, a rib that was a knife edge, and a visor that shades
    Three things the owner found by eye that no check in this repository was
    looking for, plus the permanent checks that now look for them.
    Two-clamp rework. The mount clamps the bar on both sides of the centre
    bracket instead of hanging off one. arm_crank is gone; the display centres
    itself between two mirrored pivots. The yoke grows a second female spline;
    arm_seat() becomes clamp_seat(side). Print two arms and two caps.
    The clamp-to-spline rib had collapsed to a 0.2mm knife edge. Two taper_wp()
    waypoints at the same Y cannot gain Y-thickness from a hull() between them.
    Fixed by giving the riser a real Y-span; that stage n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
    [gen4-arm.stl, gen4-brow-test.stl, gen4-cap.stl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]
2026-09-15 Measure the print orientations instead of asserting them
    docs/printing.md claimed every part prints unsupported in its stated
    orientation. That was never measured. Measured now, per part, as the area
    of surface facing steeply downward and not sitting on the plate.
    brow_test's stated orientation ("flat") turns out to be the worst of the
    six axis-aligned choices: 8874 mm^2. Standing it on its riser with the
    visor up -- the same way up as the cowl, since the visor narrows all the
    way to its tip -- is 0 mm^2. Corrected.
    The rest carry real down-facing area (cap 703, arm 1276, yoke 2644, cowl
    4902 mm^2), most of it benign: a horizontal bore's ceiling self-supports
    to 45 degrees and then bridges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
2026-09-15 Gusset the yoke: the legs hung off the plate by a 36 mm^2 shear web
    Owner, from the side view: "there is only a thin bit of plastic connecting
    where the back of the part mounts to the display to the rest of the yoke,
    this should be thicker." Right -- and the load-path section scan added
    yesterday passed it at 194.6 mm^2.
    That scan cuts perpendicular to Y, and Y is the one direction this web
    looked thick in. Stage A has to climb 13mm of Z across the 2.32mm of Y the
    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
    [gen4-arm.stl, gen4-brow-test.stl, gen4-cap.stl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]
2026-09-16 Give the cowl a fixing that exists, and fit heat-set inserts
    Owner: "how does the cowl attach? it has no bolts?" It did not.
    The cowl was held by a 1.5mm interference hook that the model's own comment
    calls "an anti-lift locator, not a structural joint (the two M3s below are
    that)". Those M3s failed twice over:
    1. The bosses were DELETED on export. Unioned into the shell, then erased
    by the cavity subtraction, which sweeps the full inset outline. The
    exported cowl's volume is identical, to 0.00 mm^3, with the boss module
    enabled and forced off.
    2. They pointed at air. x=+-52.5, z=24.5; the yoke's plate reaches x=+-51.5
    and z=0..8. Nearest yoke material to the screw'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
    [gen4-arm.stl, gen4-brow-test.stl, gen4-cap.stl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]
2026-09-16 Make the pivot bolt fittable, and rewrite the README as a spec
    "When I looked at the yoke, there was no hole to feed a bolt through."
    Correct, and three things were wrong, not one:
    1. The bore did not go through. It started at the puck's root face and ran
    outward, leaving the leg's Stage C material on the axis -- measured, a
    solid plug from x=13.75 to 17.75. 4.25mm between the bolt's tip and
    daylight.
    2. The nut had nothing square to sit on. The face it lands on wandered
    2.6mm across the nut's own footprint. A nut pulled onto a slope cocks
    and then relaxes as the ASA creeps.
    3. The head could not be inserted. The rising rib joins the arm's puck
    1.1mm prou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
    [gen4-arm.stl, gen4-brow-test.stl, gen4-cap.stl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]
2026-09-16 Root the cowl ears in the plate: they shared 2.3 mm^3 with it
    Owner, from the top view: "the new ears are barely connected." Measured,
    each ear shared 2.3 mm^3 with the bearing plate out of its own 6670 -- a
    floating wing touching at a corner.
    The plate is a truss, not a rectangle, and its outer edge runs diagonally:
    it reaches x=51.5 at y=+6, 46.0 at y=-4, 39.0 at y=-12. The ear was placed
    at y=-4 starting at x=51, which put its root five millimetres outboard of
    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
    [gen4-arm.stl, gen4-brow-test.stl, gen4-cap.stl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]
2026-09-16 Audit: a dead assertion, a stale expectation, and four wrong numbers
    A full pass over every part, joint, assertion and document.
    Found and fixed:
    - A TAUTOLOGICAL ASSERTION. "VISOR WIDER THAN THE COWL" read
    brow_edge_x + brow_d_s/2 <= disp_w/2 + reveal, and brow_edge_x is derived
    as disp_w/2 + reveal - brow_d_s/2 -- the two sides are identically equal.
    No parameter could break it. Written when brow_edge_x was independent and
    never revisited when it became derived. Replaced with two guards that do
    fail. Found by trying to break all 59 assertions; this was the only one
    that could not be broken.
    - A hardcoded 45.25 in the ear/socket clearance assert, which was
    p(holes[1])[0] + m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
    [gen4-arm.stl, gen4-brow-test.stl, gen4-cap.stl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]
2026-09-16 Sit the cowl ears on the bed: they were printing into thin air
    Owner, mid-print: "the ears are shrinking and lifting off of the plate."
    Not a settings problem.
    cowl_fix_ear_z0 was 2.5, holding each ear clear of the display "for
    safety". That left its underside 0.8-2.4mm above the bed across 21mm of
    span, sloping 5 degrees from horizontal -- a flat shelf printed into thin
    air, at the outermost corners of a 144mm ASA part, which is where shrinkage
    pulls hardest. Measured on the export, the part touched the bed only out to
    x=+-50.7 while reaching +-71.9.
    Dropped the underside to z=0, coplanar with the bearing face. The original
    reason for holding it clear does not apply to a COPLANAR surface: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
    [gen4-arm.stl, gen4-brow-test.stl, gen4-cap.stl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]
2026-09-16 Lay the arm flat: a 65mm tower on 262mm^2 was the spaghetti
    Two prints in a row failed. The geometry is clean this time -- the new
    check_print.py slices every part and confirms no layer starts in mid-air --
    but the arm's orientation was the problem.
    Standing "bore-side down" the arm is 65mm tall on 262 mm^2 of bed contact:
    4 mm^2 per mm of height, where every other part in this repository sits
    between 11 and 515. It is a tower on two thin strips.
    Laid flat, bore vertical: 868 mm^2 of contact, 18mm tall. 2.8x the grip and
    a third of the height. Two small islands (17 mm^2 each) start 2mm up and
    want support, which is a cheap trade.
    It also settles the layer-direction question printing.md ha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
2026-09-16 The yoke needs support, and check_print was measuring the wrong thing
    Owner: "im printing the yolk. it fails where the circular part sits off by
    itself" then "the edges are curling up, and the nozzle is knocking the piece
    around". Two separate things.
    check_print.py was lying. Two earlier versions asked whether a connected
    REGION of a layer touched anything below -- first "any contact at all", then
    "at least 20% held". Both reported the yoke clean, because its legs and
    discs are joined IN-LAYER to the bearing plate and the plate's area
    dominates the fraction. What the nozzle experiences is per-position: this
    bit of this layer, is there anything under it? Counting unsupported VOXELS
    instead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
2026-09-16 Land the pivot discs on a flat instead of their own tangent
    Owner: "it fails where the circular part sits off by itself", then "can we
    make the circular part that is nearest the bed connect to it flat? that
    would fix it". Right on both counts.
    The tangency was deliberate. yoke_standoff was raised to 12 specifically to
    put the Ø40 disc's lowest point at exactly z=0 -- its own comment reads
    "touching, not clipping". That solved clipping the bed and created the worst
    possible first layer: a 40mm disc balanced on a mathematical line. The two
    discs shared 184 mm^2 of first-layer contact between them.
    A small foot now fills the lens between bed and arc, so each disc lands on a
    real 16 x 10.6mm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
    [gen4-arm.stl, gen4-brow-test.stl, gen4-cap.stl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]
2026-09-16 Sweep every part for the tangent problem: the cowl and cap needed work
    The cowl is the worst in the set despite the best bed adhesion (11807 mm^2).
    4472 mm^2 is laid over air, dominated by a single 2092 mm^2 region beginning
    22.4mm up -- the visor's riser is full width and reaches 12.5mm past the
    box's own top edge, so it appears in mid-air -- plus 1183 mm^2 more at
    30.4mm as the visor carries on past the front rim. Nothing is under either
    down to the bed, so build-plate-only support reaches them. printing.md now
    states the cowl requires support instead of listing a down-facing area and
    deferring to a slicer preview.
    The cap gets laid flat, the same rotation as the arm: 312 -> 868 mm^2 on t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
    [gen4-arm.stl, gen4-brow-test.stl, gen4-cap.stl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]
2026-09-17 Keep the arm's rib out of the spline mate
    Owner, looking at the part: "there is a solid rectangle that will prevent the
    arm grooves from interlocking with the yoke grooves." Correct, and it is
    literally a rectangle -- taper_wp()'s own profile is one.
    The rising rib ran from y=2 to y=16 while the male spline's root plane is
    arm_pivot_y=9, so 7mm of it stood proud of the mating face, straight into the
    volume the yoke's female disc occupies. Rod probe in the arm's own frame:
    2.45mm proud over a ~60 degree sector. In the assembled frame, 3.45mm of
    interference over ~120 degrees. The joint could not close.
    Narrowing the rib's top waypoints to y=9..15 was NOT enough -- it only fell to
    1.10mm, be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
    [gen4-arm.stl, gen4-display-mount.scad]
2026-09-18 The pivot print-foot was filling the spline's tooth valleys
    Owner: "the yolk is still not right. there is material in the way of the yolk
    mating with the arm correctly and flat." Right, and it was the foot I added
    yesterday to stop the Ø40 disc printing on its own tangent.
    That foot spanned the full disc stack in X -- yoke_tip_h + base_female +
    spline_h -- so it reached the tooth crest plane and filled the VALLEYS across
    roughly a 40 degree sector at the bottom of the disc. Measured on the export:
    the yoke's face at r=19 read x=28.45 through that sector where every other
    angle reads 26.75, the valley floor. The male teeth had a full tooth height of
    material in the way and the joint could n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
    [gen4-display-mount.scad, gen4-yoke.stl]
2026-09-18 Raise spline_id to 24 so every tooth is coarser than the nozzle
    Owner, on a printed arm: "why does the height lower towards the center of the
    circle?" It does not -- the model holds the teeth at a constant 1.60mm from
    r=7 through r=19, measured. What lowers is the PITCH.
    The teeth are a triangular wave in theta at constant height, so 48 of them
    crowd into a shrinking circumference as you move inward. At spline_id=12 the
    pitch at the bore was 0.79mm: each valley 0.39mm wide and 1.6mm deep, narrower
    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
    [gen4-arm.stl, gen4-display-mount.scad, gen4-spline-test.stl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]
2026-09-18 Wire the mate test into the build; stop it crashing the machine
    check_mate.py was written for the one part pair build.sh deliberately never
    intersected -- yoke vs arm, where a whole-ring boolean lies -- and was then
    never called. Skipping the boolean had already been taken as licence to skip
    the check once, and a 3.45mm interference shipped. It is now a gate.
    It also can no longer take the machine down. It used mesh.contains(), which
    on this box (no embree) fires a diagonal ray from every sample point; a
    diagonal ray's bounding box spans much of the mesh, so memory grows as
    points x candidate triangles. One 26,400-point call against the 135k-
    triangle yoke exhausted 31 GB with no swap and c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
    [gen4-yoke-leg-test.stl]
